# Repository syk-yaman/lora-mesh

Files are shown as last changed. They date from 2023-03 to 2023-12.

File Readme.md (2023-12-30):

# LoRaMesh: a LoRa mesh network deployed in the Olympic Park, London to sense weather parameters

##### A dissertation for an MSc degree in [Connected Environments](https://connected-environments.org/) at [University College London](https://www.ucl.ac.uk/prospective-students/graduate/taught-degrees/connected-environments-msc), 2022/2023.

This project uses [OpenThread](https://openthread.io/) in LoRa to sense humidity, temperate and light in the Queen Elizabeth Olympic Park (QEOP), London. Sensor data is visualised via web dashboards and projected on a physical Olympic Park table using projection mechanism.

| Mesh node | The Data Table |
| :---: | :---: |
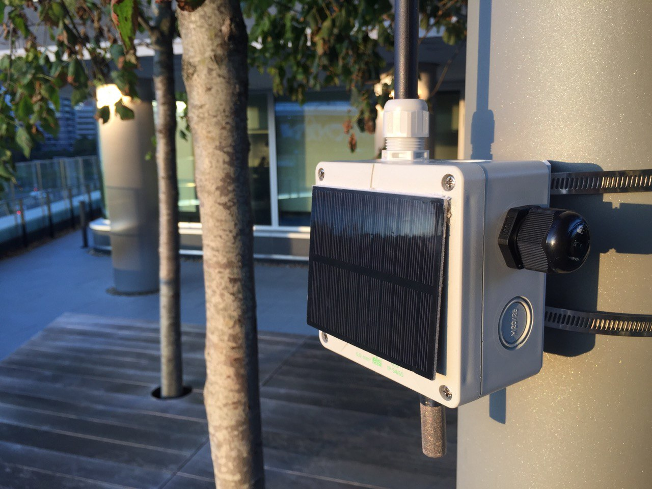
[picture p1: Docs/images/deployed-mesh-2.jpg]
Deployed mesh node in the Olympic Park
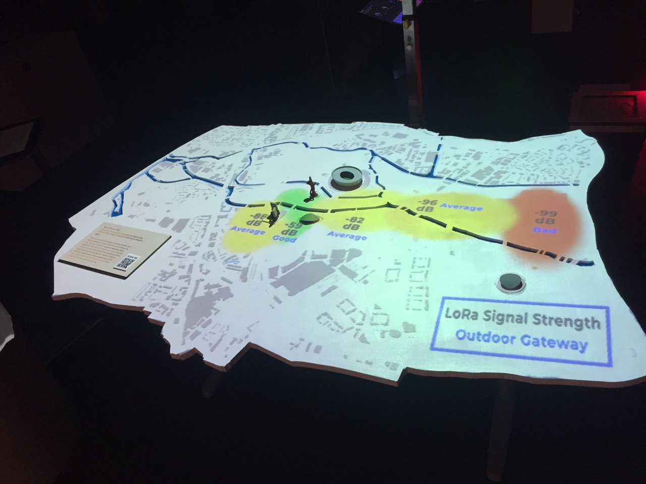
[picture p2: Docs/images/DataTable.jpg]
The Data Table
|  |  |

## Repository Content Summary

1. **Assets**

   This folder includes the 3D printed parts, namely Fusion360 project files and STLs for the enclosures and the 3D objects for the Data Table.

   - [QEOP 3D Models](</Assets/QEOP 3D models/>)
   - [LoRa Gateway 3D Enclosures](</Assets/3D Enclosures/>)

2. **Code**

   Includes micro-controllers' code, Artificial Intelligence code and various assets used during development.

   - [Lopy4](/Code/Lopy4)

     The main Micro Python code for the Lopy4, which uses Open Thread for LoRa mesh.

   - [Current Analysis](/Code/Current%20Analysis)

     Contains the code, schematic and results for the real-time current analysis circuit.

   - [Heatmap](/Code/Heatmap)

     Web page that visualises CSV data for LoRa heatmap in the Olympic Park.

   - [VR Headset](/Code/VR%20Headset)

     A web page built using [A-Frame](https://aframe.io/) to visualise 360 videos of the QEOP on VR Headsets.

   - [Data Table](</Code/DataTable>)
     The data files projected on the physical map including the final calibrated [Base Map](/Code/DataTable/BaseMap.jpg).

3. **Datasets**

   The final datasets as an outcome of this project. There is a [detailed description](/Datasets/Readme.md) available for each dataset.
   
4. **Docs**

   This folder holds different kinds of documentation and images produced during project life time.

5. **PCB**

   The electronic side of the project. This section contains Eagle files and CAM outputs sent to PCB manufacturers. Also, a [CNC manufacturing tutorial](/PCB/CNC) is available.

6. **Server**

   Docker Composer file for InfluxDB, Grafana and MQTT broker. Basically, all data acquisition is being managed by this Docker image.

7. **Experiments**
   This section includes the multiple experiments done throughout the project.

   - [Experiment #1](/Experiments/Experiment1): First heatmap between LoRa indoor gateway and MRK1310.
   - [Experiment #2](/Experiments/Experiment2): Heatmap between two LoRa nodes (Both MRK1310).
   - [Experiment #3](/Experiments/Experiment3): Heatmap between two LoRa nodes (Both Lopy4), contains a [geolocated dataset](/Experiments/Experiment3/Results/heatmap/Experiment3-LoRa-RSSI-heatmap-QEOP-OPS.csv).
   - [Experiment #4](/Experiments/Experiment4): Contains a [topographic study](/Experiments/Experiment4/GIS%20Stratford) using QGIS, and a [detailed deployment plan](/Experiments/Experiment4/Deployment%20plan) for LoRa nodes in the QEOP.
   - [Experiment #5](/Experiments/Experiment5): Basic Pymesh experiments. 
   - [Experiment #6](/Experiments/Experiment6): Basic MQTT experiments.

## Project Overview

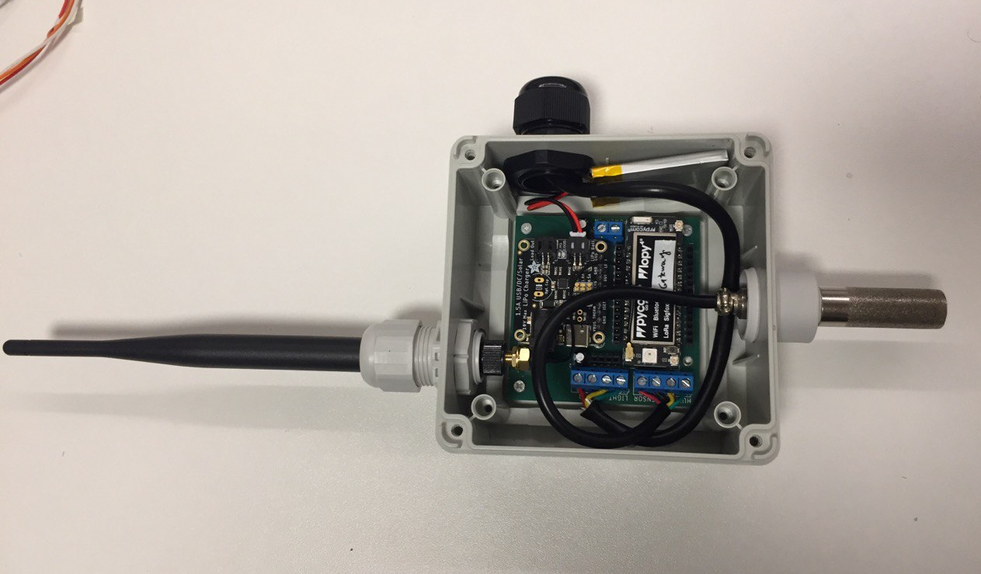
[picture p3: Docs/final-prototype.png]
Final prototype


<p align="center">
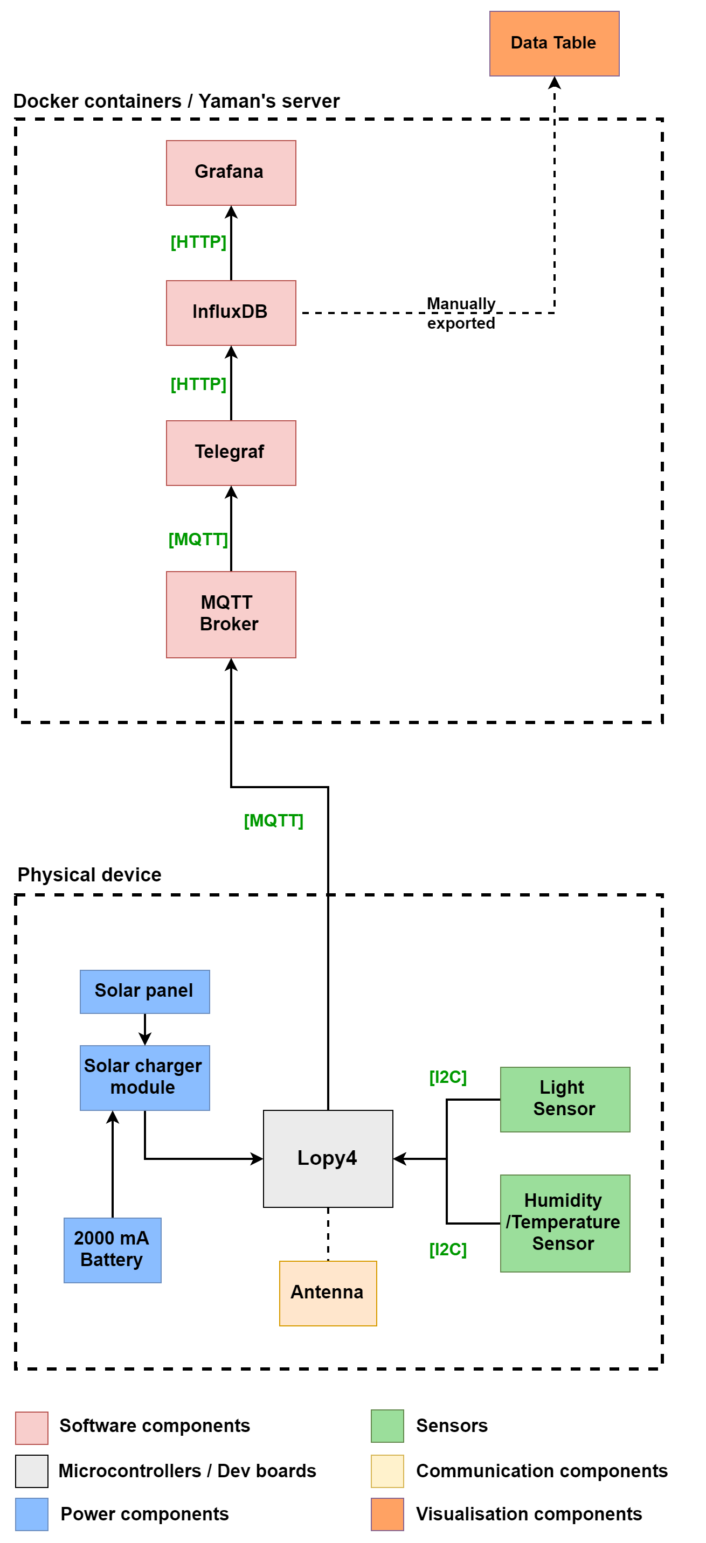
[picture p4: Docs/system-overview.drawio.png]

</p>

## Building

### Used components and tools

Hardware:

* [Lopy4](https://www.adafruit.com/product/3689): a dev kit based on ESP32 that has LoRa, Wifi, Sigfox and Bluetooth communication capability.
* [SHT-30](https://www.adafruit.com/product/4099): a weatherproof humidity and temperature sensor.
* [Gravity SEN0562](https://www.dfrobot.com/product-2664.html): a weatherproof light sensor.
* [DC Solar charger (BQ24074)](https://www.adafruit.com/product/4755)
* [Solar panel](https://coolcomponents.co.uk/products/solar-panel-1-watt): 1 Watt, 10x80 cm.
* 2000 mA 3.7v battery

Software:

 - [InfluxDB](https://www.influxdata.com/)
 - [Telegraf](https://www.influxdata.com/time-series-platform/telegraf/)
 - [Grafana](https://grafana.com/)
 - [Docker Compose](https://docs.docker.com/compose/)

All the software applications are packed into one [Docker image](/Server/docker-compose.yml) that you can use easily.

### Hardware PCB and schematic

<p align="center">
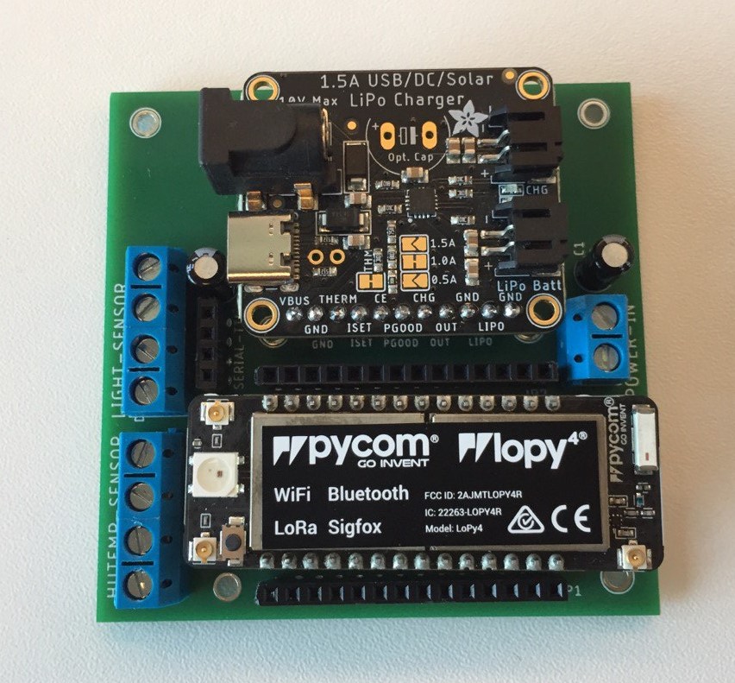
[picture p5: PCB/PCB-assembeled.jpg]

</p>

<p align="center">
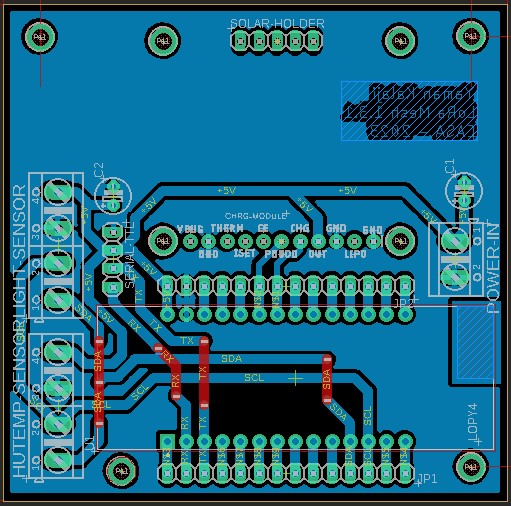
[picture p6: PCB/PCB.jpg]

</p>

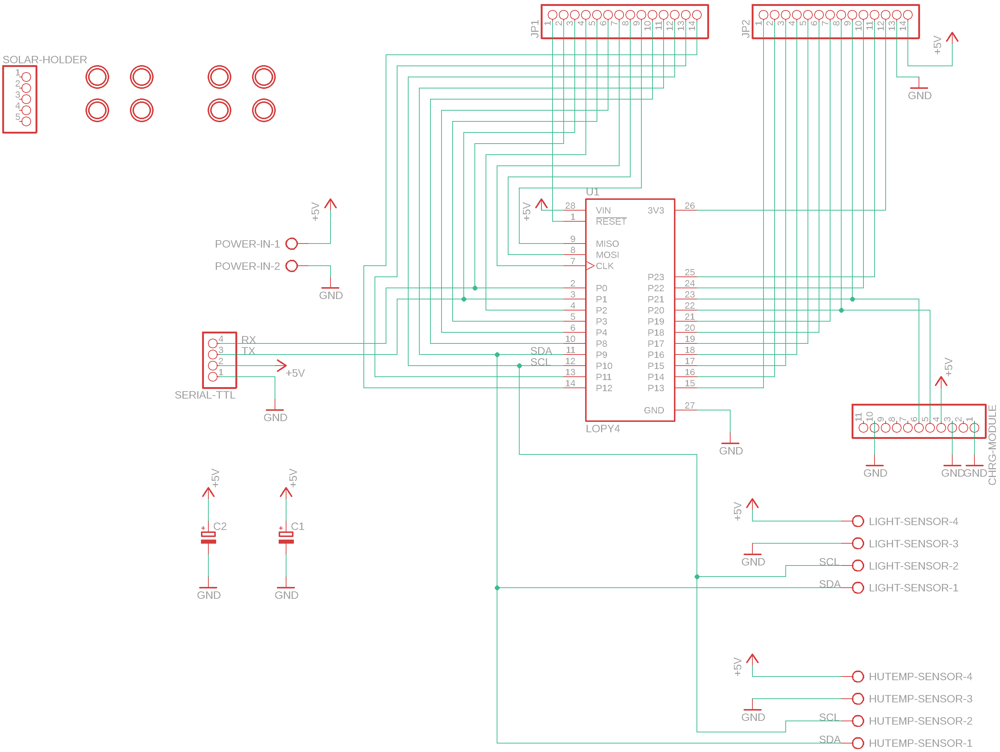
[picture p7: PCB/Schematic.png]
Hardware schematic


## Results

#### The Data Table

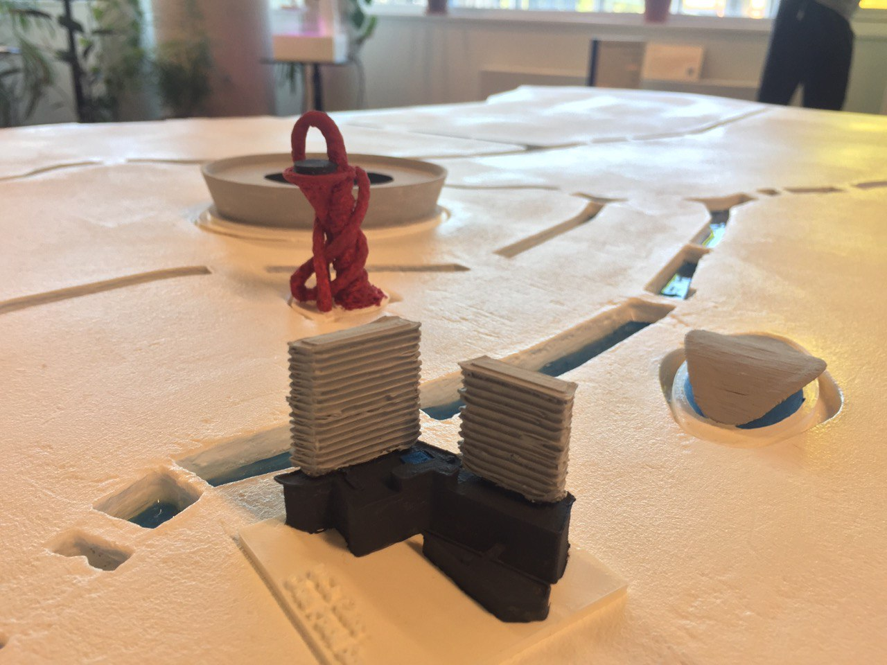
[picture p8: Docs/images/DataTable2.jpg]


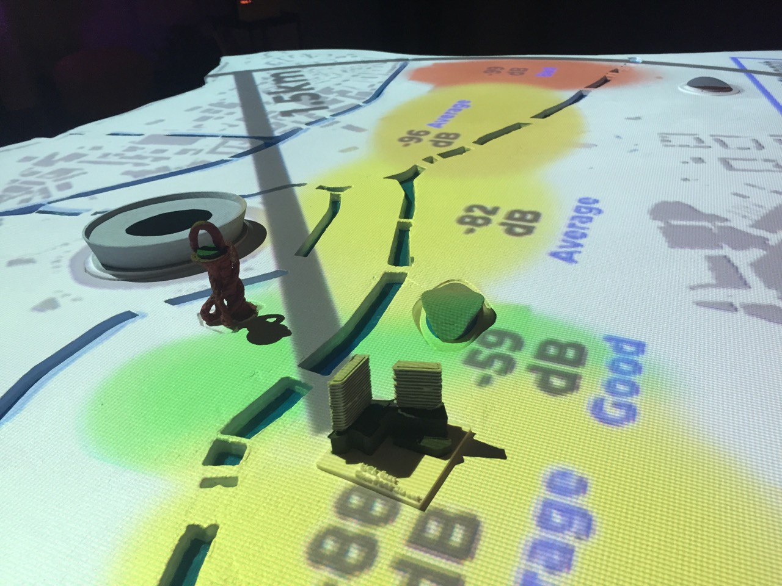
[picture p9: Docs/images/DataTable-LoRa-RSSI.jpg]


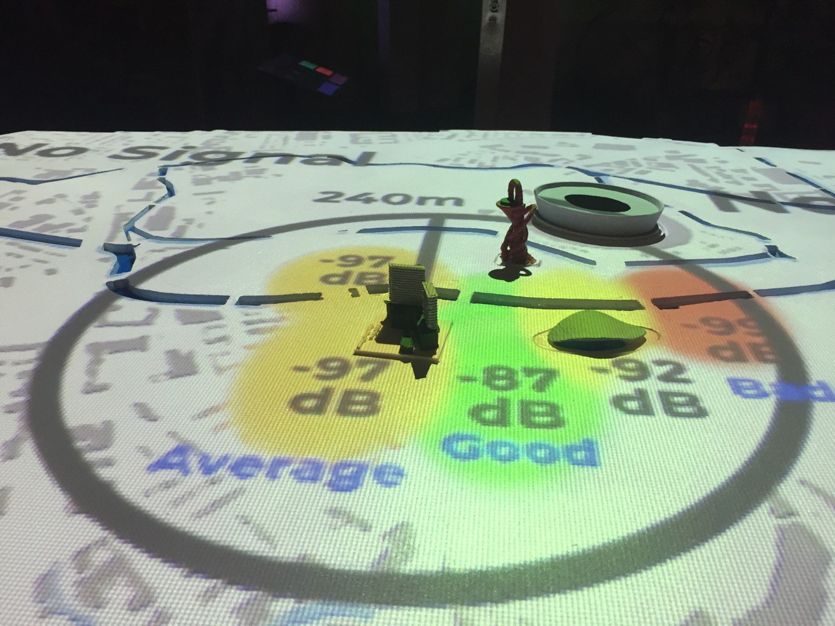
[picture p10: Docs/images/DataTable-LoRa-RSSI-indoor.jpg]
 



#### Grafana Dashboard

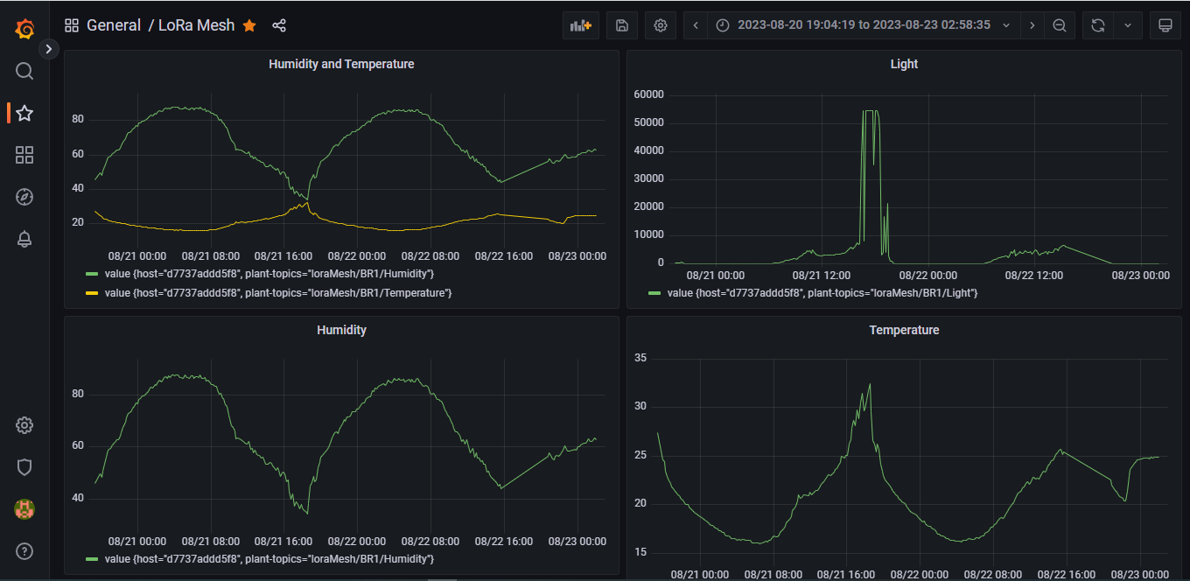
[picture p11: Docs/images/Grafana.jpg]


#### Heatmaps

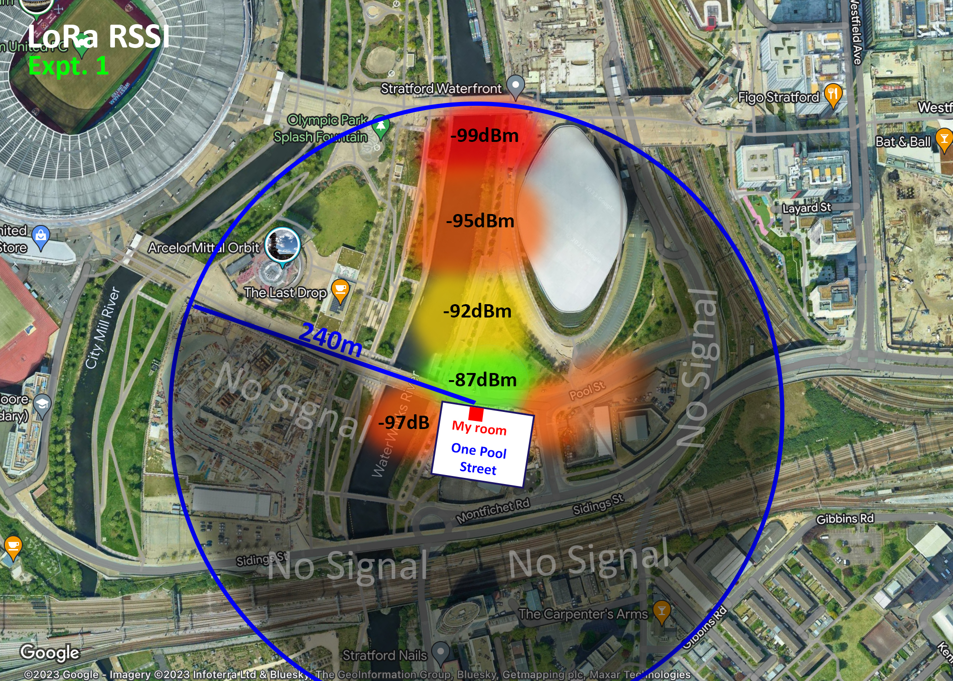
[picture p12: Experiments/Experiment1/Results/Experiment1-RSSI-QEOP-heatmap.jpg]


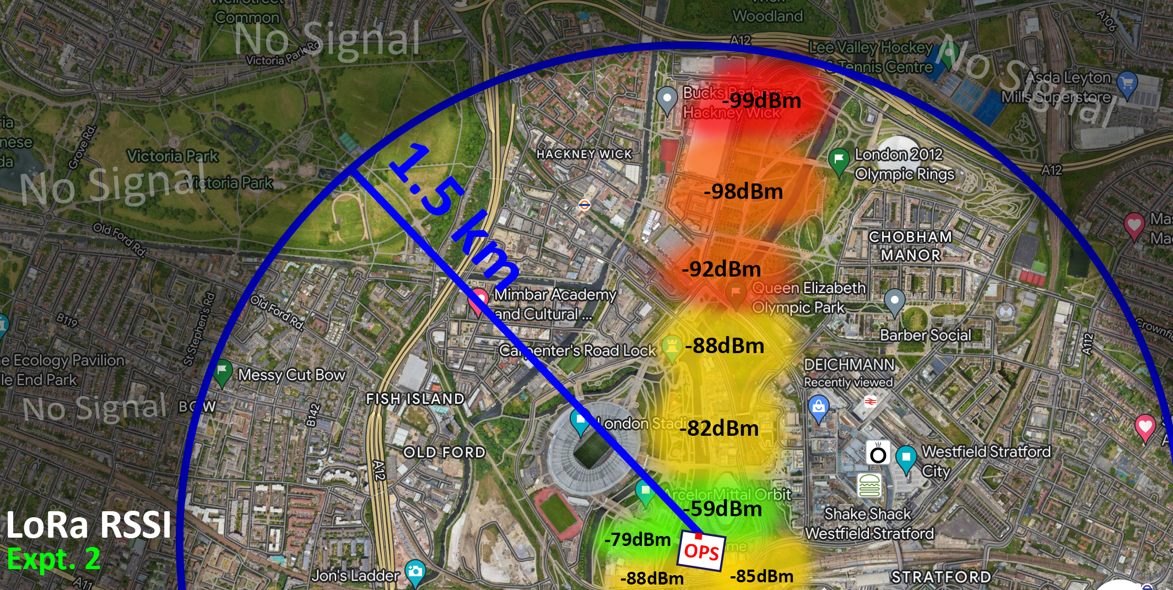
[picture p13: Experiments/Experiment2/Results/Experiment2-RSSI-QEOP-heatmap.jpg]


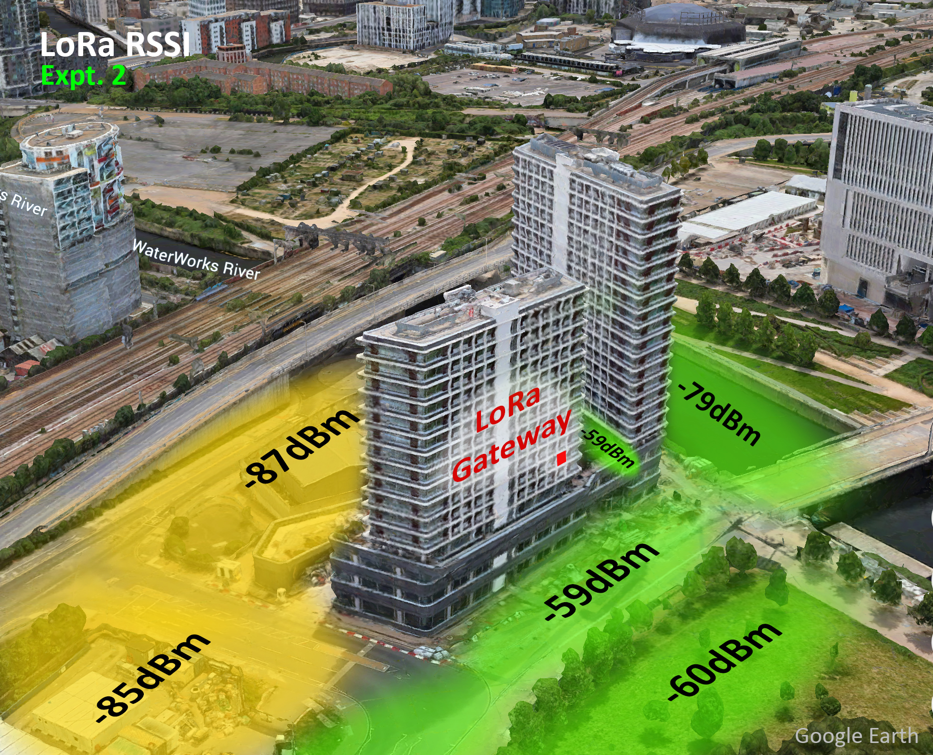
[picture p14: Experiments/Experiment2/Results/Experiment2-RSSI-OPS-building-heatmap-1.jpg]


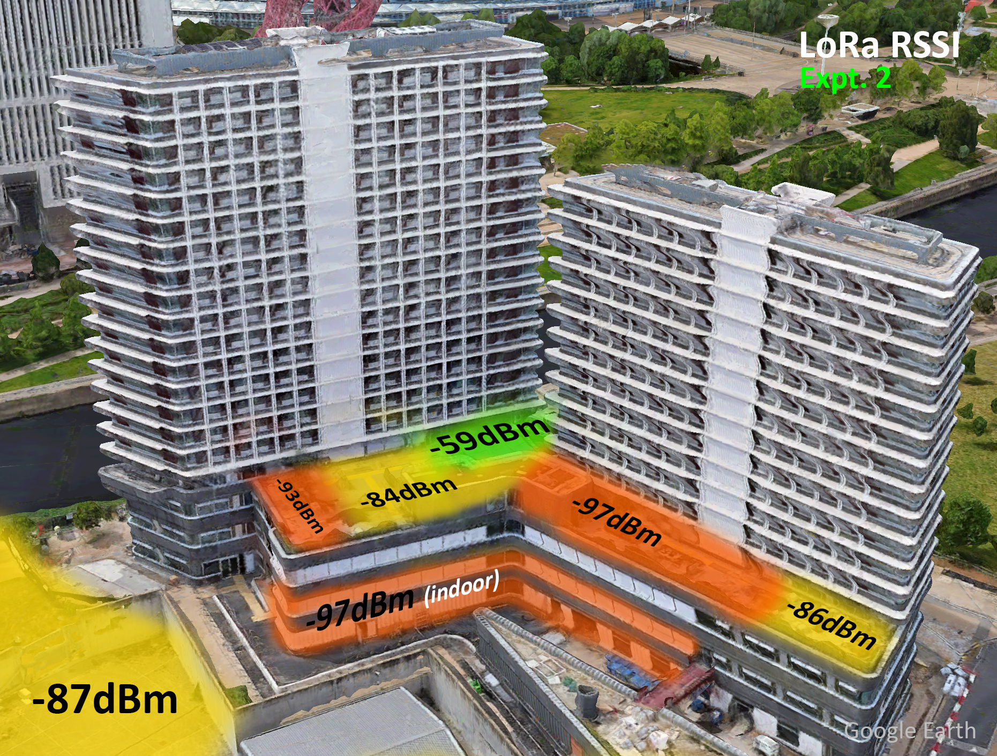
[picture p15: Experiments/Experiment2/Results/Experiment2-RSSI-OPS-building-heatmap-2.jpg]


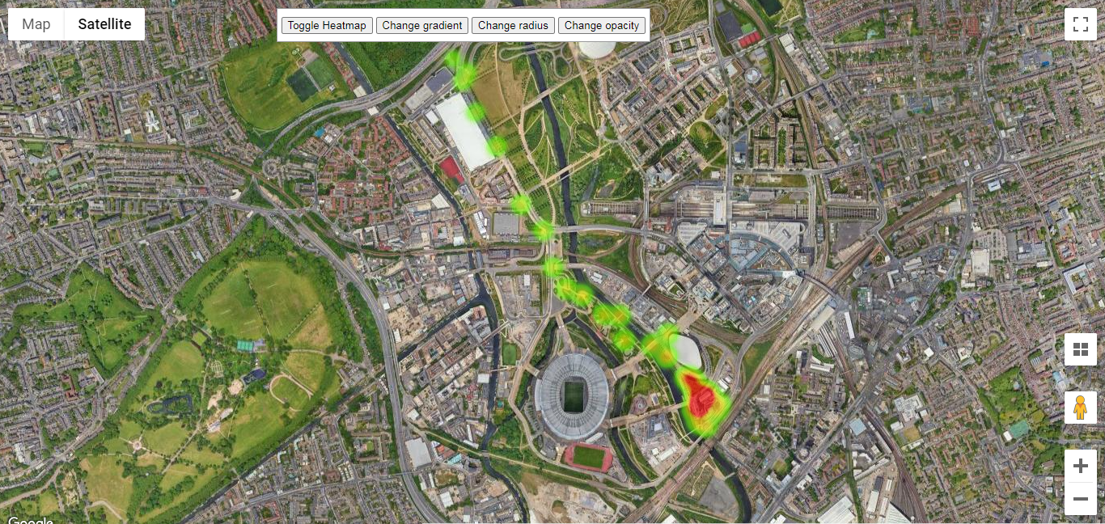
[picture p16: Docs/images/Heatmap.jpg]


#### Current consumption analysis

<p align="center">
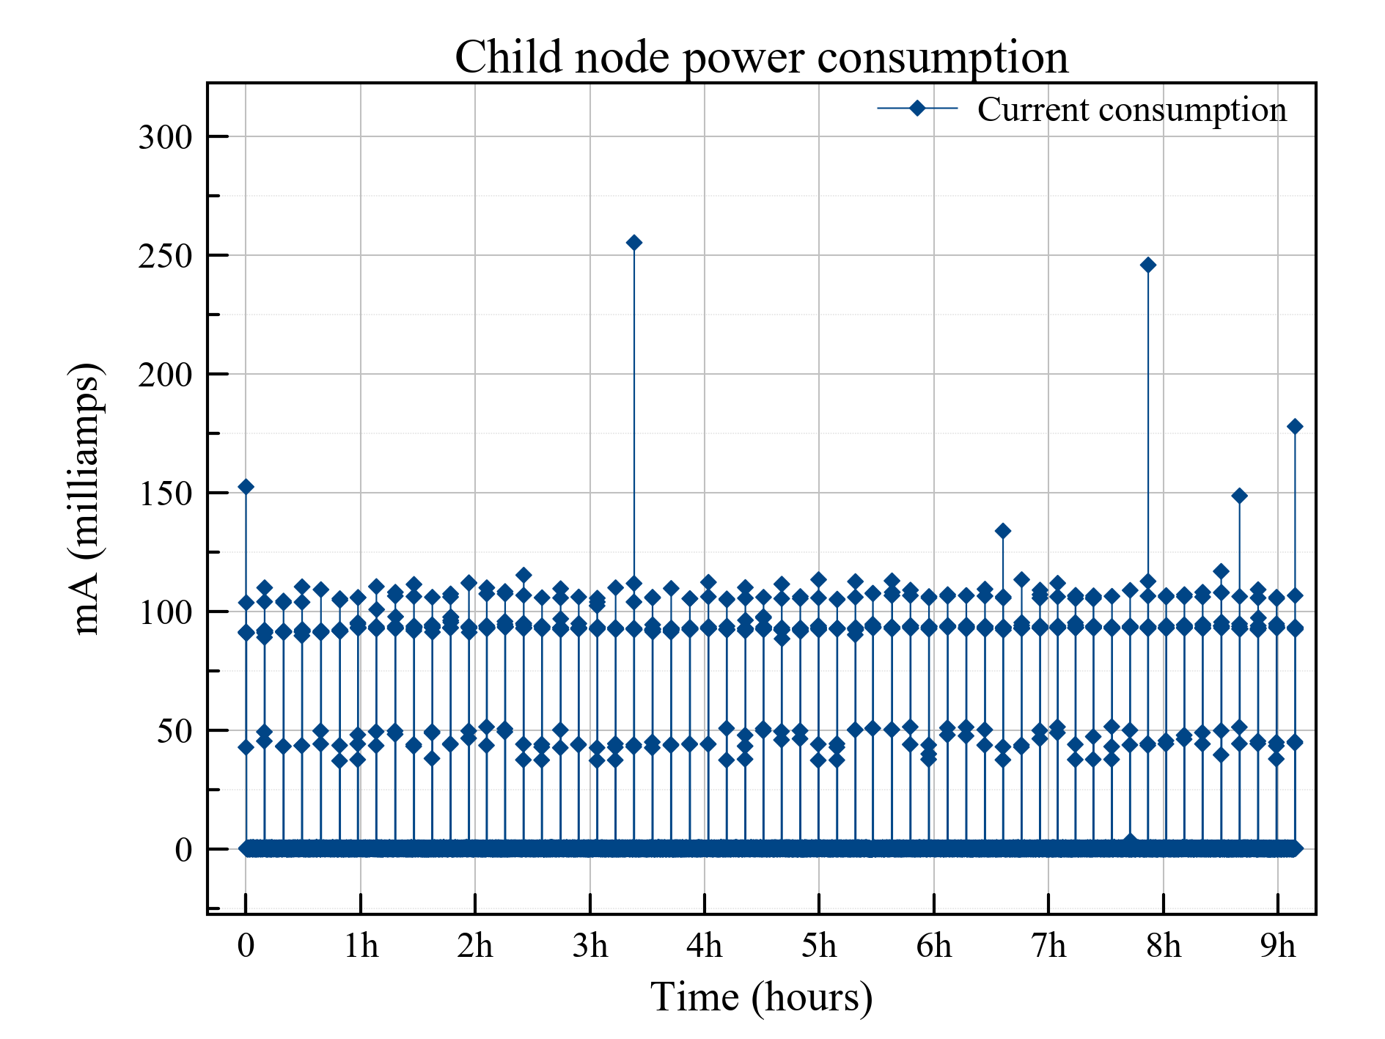
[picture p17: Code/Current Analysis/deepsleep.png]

</p>

<p align="center">
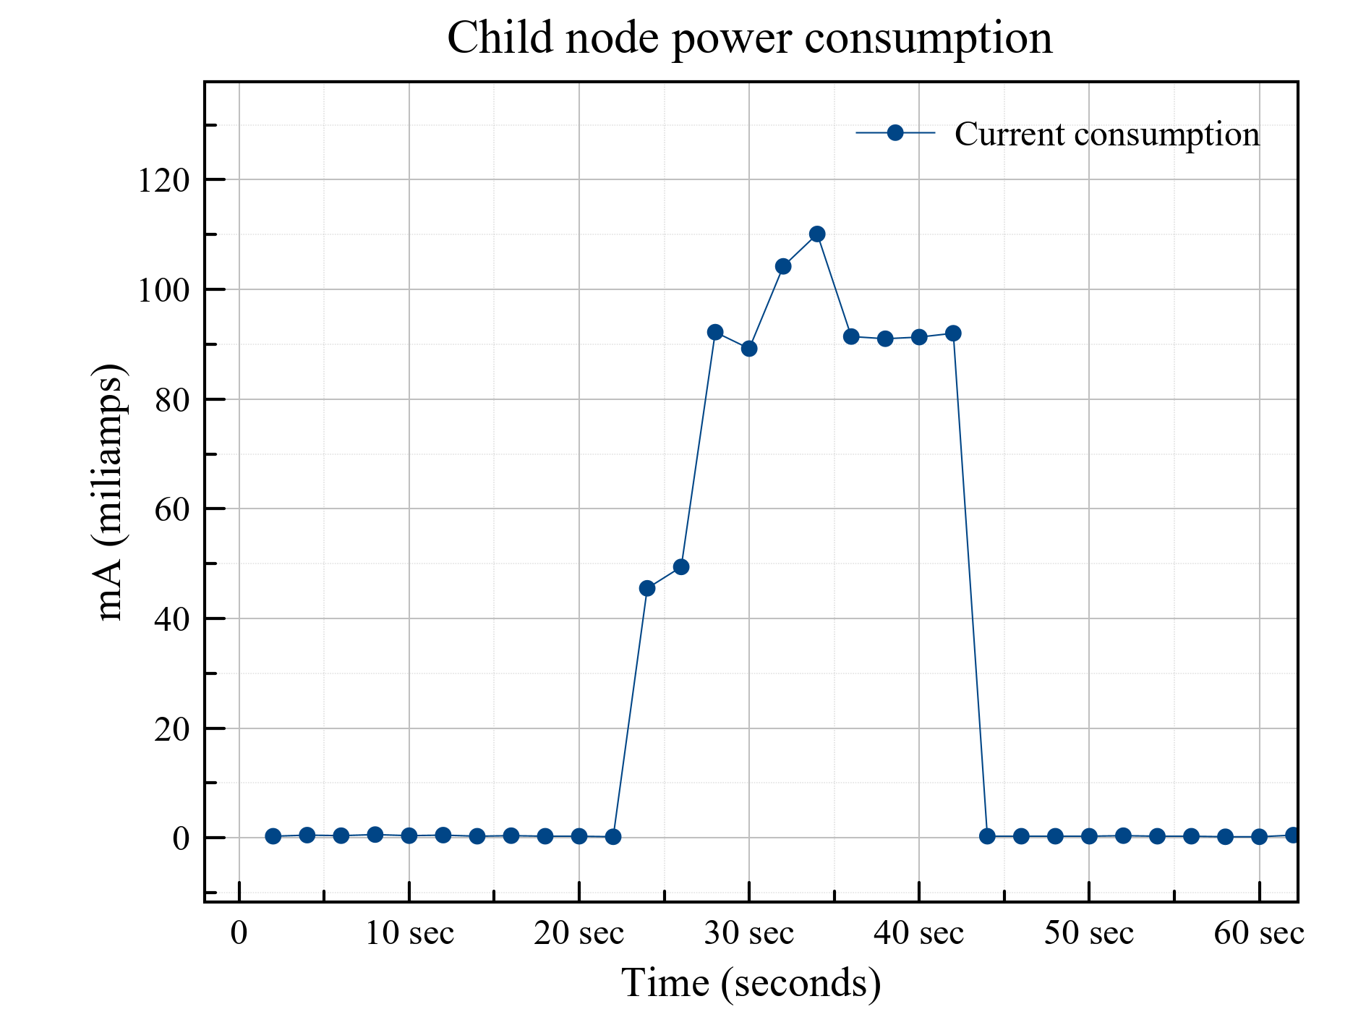
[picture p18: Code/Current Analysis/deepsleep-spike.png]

</p>

<p align="center">
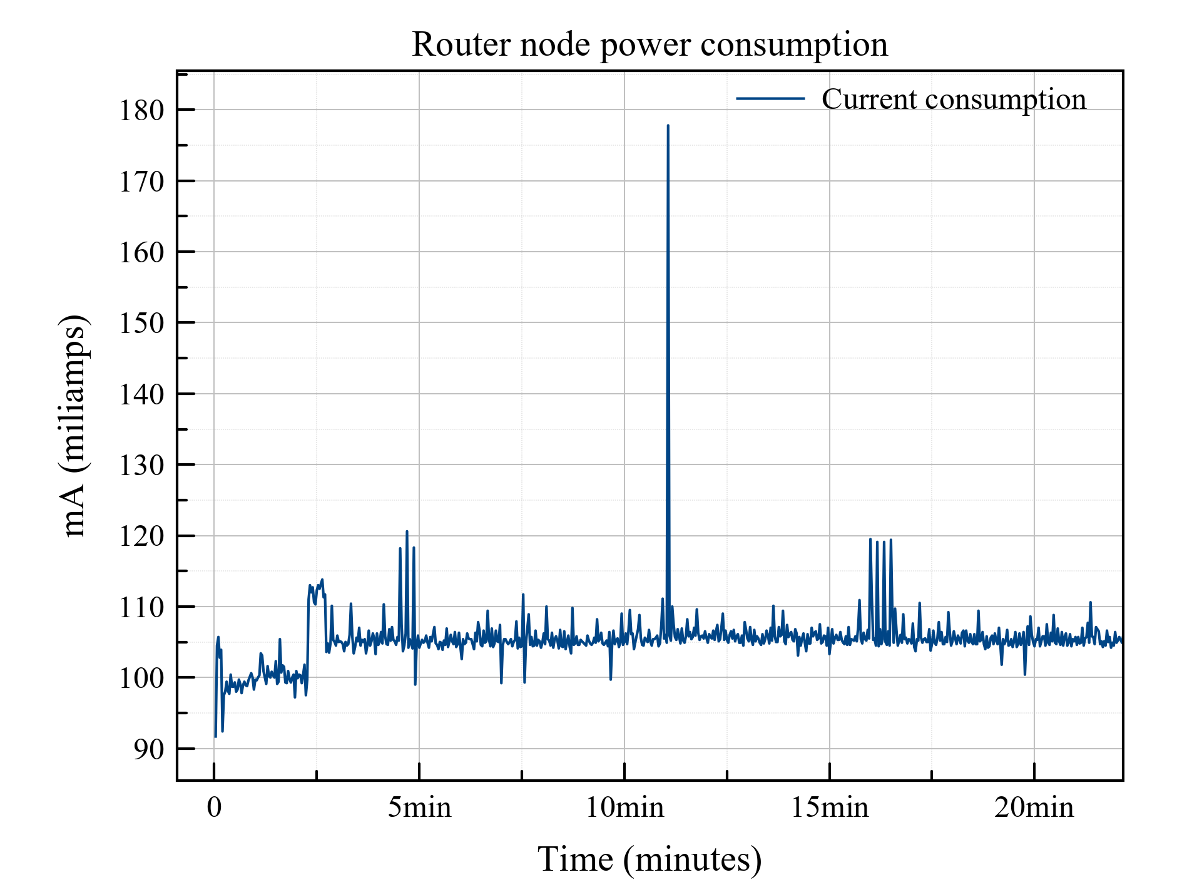
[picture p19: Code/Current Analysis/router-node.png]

</p>

## License

###### The software side is licensed under MIT License

```
MIT License

Permission is hereby granted, free of charge, to any person obtaining a copy
of this software and associated documentation files (the "Software"), to deal
in the Software without restriction, including without limitation the rights
to use, copy, modify, merge, publish, distribute, sublicense, and/or sell
copies of the Software, and to permit persons to whom the Software is
furnished to do so, subject to the following conditions:

The above copyright notice and this permission notice shall be included in all
copies or substantial portions of the Software.

THE SOFTWARE IS PROVIDED "AS IS", WITHOUT WARRANTY OF ANY KIND, EXPRESS OR
IMPLIED, INCLUDING BUT NOT LIMITED TO THE WARRANTIES OF MERCHANTABILITY,
FITNESS FOR A PARTICULAR PURPOSE AND NONINFRINGEMENT. IN NO EVENT SHALL THE
AUTHORS OR COPYRIGHT HOLDERS BE LIABLE FOR ANY CLAIM, DAMAGES OR OTHER
LIABILITY, WHETHER IN AN ACTION OF CONTRACT, TORT OR OTHERWISE, ARISING FROM,
OUT OF OR IN CONNECTION WITH THE SOFTWARE OR THE USE OR OTHER DEALINGS IN THE
SOFTWARE.
```

###### The hardware side is licensed under CERN License

```
This documentation describes Open Hardware and is licensed under the CERN OHL v. 1.2.

You may redistribute and modify this documentation under the terms of the CERN OHL v.1.2. (http://ohwr.org/cernohl). This documentation is distributed WITHOUT ANY EXPRESS OR IMPLIED WARRANTY, INCLUDING OF MERCHANTABILITY, SATISFACTORY QUALITY AND FITNESS FOR A PARTICULAR PURPOSE. Please see the CERN OHL v.1.2 for applicable conditions
```

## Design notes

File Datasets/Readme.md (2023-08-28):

# Datasets description

| Dataset name | Description | Unit | Related to | Visualisation |
| :---: | :---: | --- | --- | --- |
| [LoRa-RSSI-heatmap-QEOP-OPS-Lopy4.csv](/Datasets/LoRa-RSSI-heatmap-QEOP-OPS-Lopy4.csv) | An RSSI heatmap in the Queen Elizabeth Olympic Park, London between two LoRa nodes (Pycom Lopy4).<br />The first node is static on the 5th floor at One Pool Street building (Tower 2), the second one is portable. | dBm | [Experiment #3](/Experiments/Experiment3) | <br />[Heatmap webpage](/Code/Heatmap)<br /><br /><br /><br />[DataTable](/Code/DataTable) |
| [Current-Analysis-Border-Router-Node.csv](/Datasets/Current-Analysis-Border-Router-Node.csv) | Current consumption in mA for a border router node in the LoRa mesh network | mA | [Current Analysis](/Code/Current%20Analysis) |  |
| [Current-Analysis-Child-Node-with-deep-sleep.csv](/Datasets/Current-Analysis-Child-Node-with-deep-sleep.csv) | Current consumption in mA for a child node router in the LoRa mesh network (with two sensors attached) | mA | [Current Analysis](/Code/Current%20Analysis) | <br /><br /> |
| [Humditiy-QEOP-2023-08-20-to-2023-08-23.csv](/Datasets/Humditiy-QEOP-2023-08-20-to-2023-08-23.csv) | Outdoor humidity readings in the Queen Elizabeth Olympic Park, London. Sensor deployed in One Pool Street building | RH (%) | N/A |  |
| [Temperature-QEOP-2023-08-20-to-2023-08-23.csv](/Datasets/Temperature-QEOP-2023-08-20-to-2023-08-23.csv) | Outdoor temperature readings in the Queen Elizabeth Olympic Park, London. Sensor deployed in One Pool Street building | Celsius  | N/A |  |
| [Light-QEOP-2023-08-20-to-2023-08-23.csv](/Datasets/Light-QEOP-2023-08-20-to-2023-08-23.csv) | Outdoor light readings in the Queen Elizabeth Olympic Park, London. Sensor deployed in One Pool Street building | Lux (lx) | N/A |  |

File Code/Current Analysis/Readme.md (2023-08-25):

Current measurment interval is 2 seconds

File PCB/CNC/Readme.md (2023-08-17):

## Guidelines for PCB Manufacturing using a CNC:

This is a general guide how to manufacture a PCB using a CNC. This guideline is also available and being always updated on [LoRa Mesh Github Repo](https://github.com/syk-yaman/lora-mesh/tree/master/PCB/CNC).

### Tools needed/used:

1. CNC machine: [Carvey](http://carvey-instructions.inventables.com/) from Inventables is used for this manual.
2. [FlatCam](http://flatcam.org/) to convert Gerber files to G-code. **Important note:** Only FlatCam v8.5 is compatible with Carvey machines, you can download the older version from [here](https://bitbucket.org/jpcgt/flatcam/downloads/).
3. [Autodesk Eagle](https://www.autodesk.com/products/eagle/overview?term=1-YEAR&tab=subscription) or any PCB CAD software, this method works for all of them!
4. [Easel software](https://easel.inventables.com/) to connect to the Carvey CNC machine, it's a web application without installation. A free plan would probably works fine.

### Steps in Eagle:

After finishing your design and heading to the CAM Processor, choose the `example_2_layer.cam`.

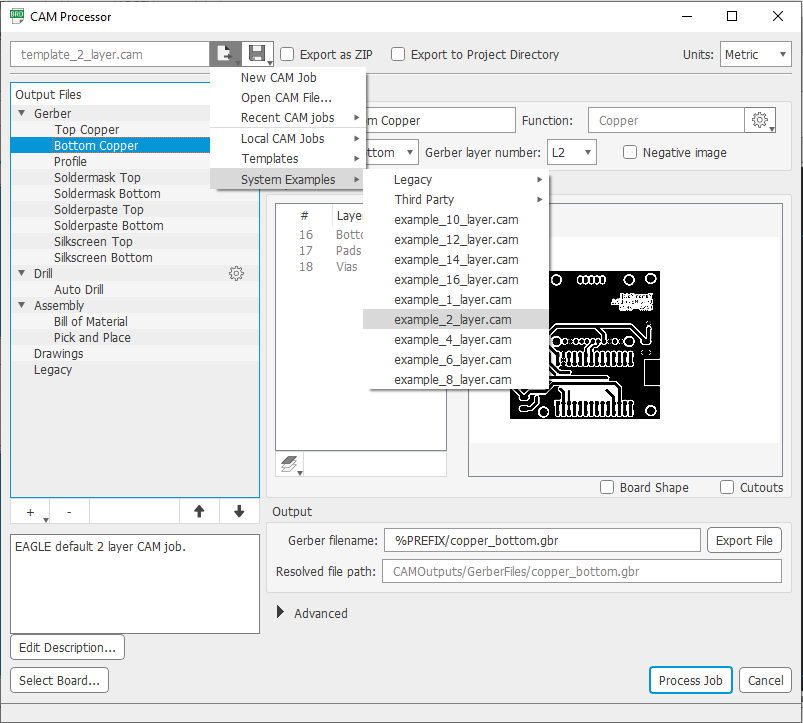
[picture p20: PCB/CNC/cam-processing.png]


After processing the job, the output files that we are interested in are:

- `copper_bottom.gbr` in `GerberFiles` folder.
- `copper_top.gbr` in `GerberFiles` folder, if it's a two-layers PCB.
- `drill_1_16.xln` in `DrillFiles` folder.

Those files are to be imported to FlatCam.

### Steps in FlatCam:

Basically, it's best to follow this video:

[How NOT to Mill a PCB (except for SMD)](https://www.youtube.com/watch?v=_ak0IJUMBFg)

And for extra information, those videos could also be assisting:

[CNC Milling Double Sided PCBs Using Eagle, FlatCam and GRBL/Candle, Step by Step Detailed Guide](https://www.youtube.com/watch?v=9xczeQMj2dg&t=375s)

[Eagle CadSoft + FlatCam CNC Gcode](https://www.youtube.com/watch?v=p3YzVjpt9Ig&t=794s)

#### Important notes:

1. **Don't forget** to mirror the bottom layer, this is not mentioned in the previous videos.

2. For the Carvey CNC, please change these settings as follows:

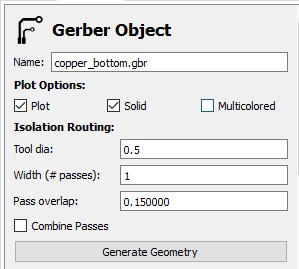
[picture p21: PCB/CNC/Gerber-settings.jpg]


Some explanations:

* **Tool dia**: diameter of the cutting tool, to be changed **<u>once for every generated G-code</u>**, this means if you have multiple paths with multiple widths, you need to create a G-code for each separately. 

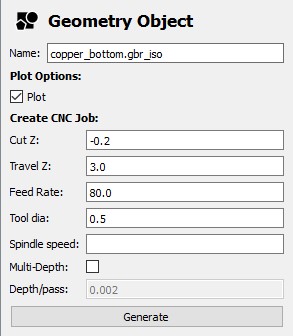
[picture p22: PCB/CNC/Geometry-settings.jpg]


Some explanations:

- **Cut Z**: this is related to the height between the drilling bit and the PCB, which is according to my experiments should be -0.2. If you notice the drilling bit is not touching the PCB, or the copper layer gets pushed too much, try to adjust this accordingly.
- **Travel Z**: the height of the drill when it moves from one position to another on the PCB. Making this 3 helps in taking less time.
- **Feed Rate**: cutting speed, try to lower it down if you notice the copper edges are not smooth enough.
- **Tool dia**: this is just for display, it was originally set in the previous photo.  

### Steps in Easel:

Basically, just import the generated G-code from FlatCam to Easel. No need for any further settings here, the imported G-code contains all the required settings. Hit Carve and go! - don't forget to watch the first couple of minutes to make sure the CNC is executing the job correctly.

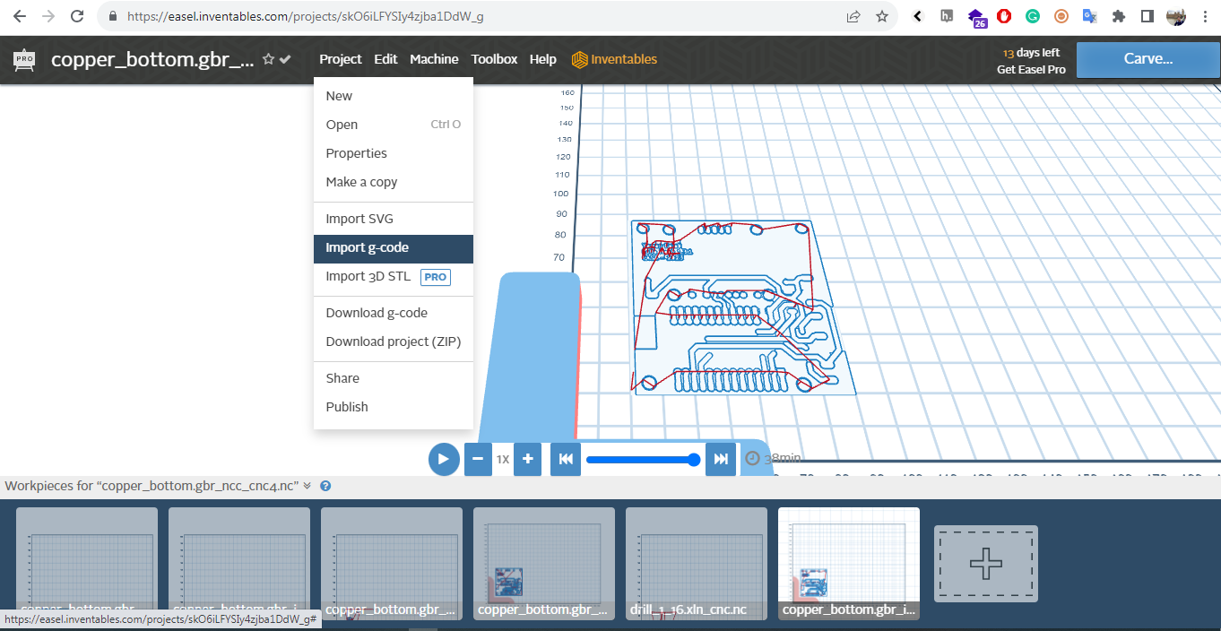
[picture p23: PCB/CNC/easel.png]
easel


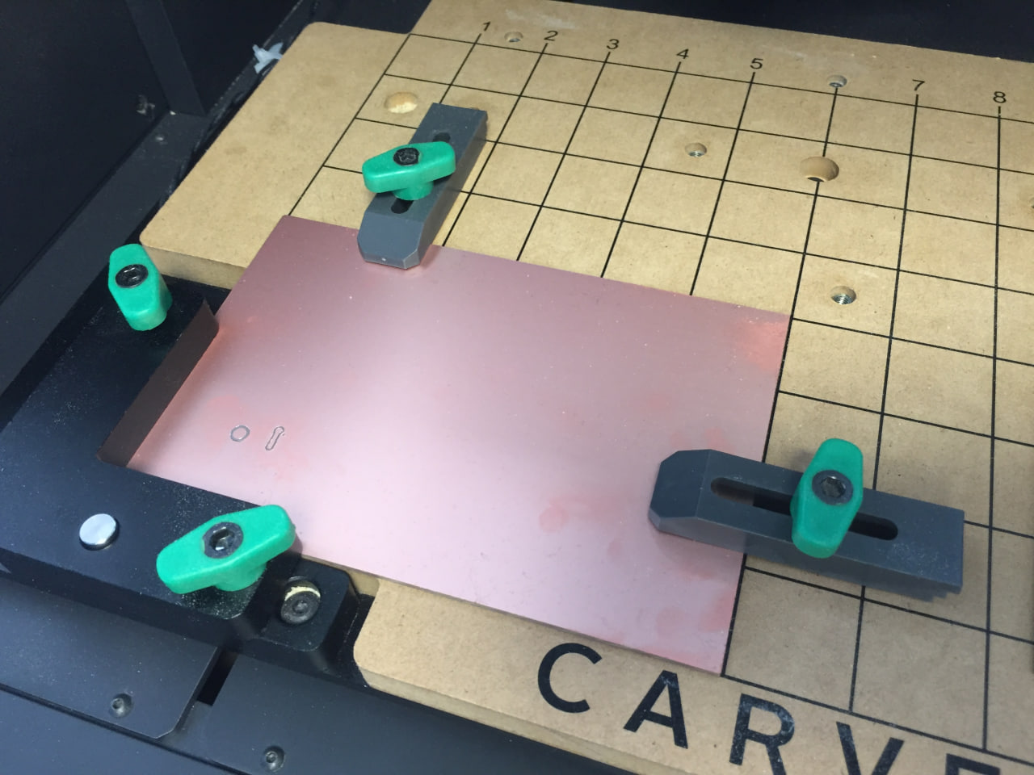
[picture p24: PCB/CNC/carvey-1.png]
carvey-1


**Note:** try to not fix the PCB from its edges but only from long edges, as doing this would make it curve from the centre thus not having the same height everywhere.

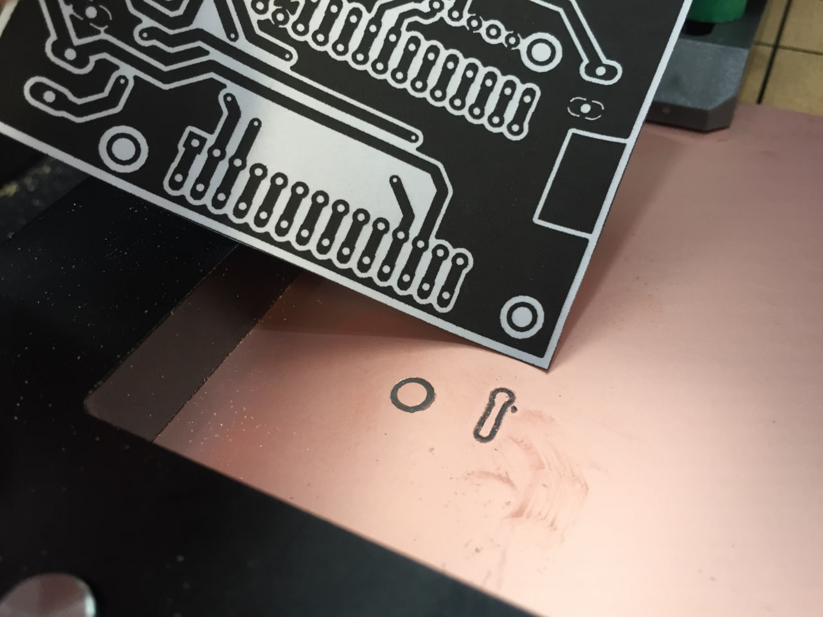
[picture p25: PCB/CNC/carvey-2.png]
carvey-2


## Further notes to be added after continuing the experiments.

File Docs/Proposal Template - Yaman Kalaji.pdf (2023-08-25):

### Working Title

Power analysis of an autonomous LoRa mesh network for rural agriculture environment

### Hypothesis or Research Question

Can we rely on an autonomous LoRa mesh sensor network to work efficiently in distant areas without network or electricity infrastructure? What is the power performance of mesh nodes in this case?

### Background

LoRa sensor networks work best when surrounded by gateways, but this tends to be difficult or extremely costly in certain situations where no network or electrical infrastructure is available, such as vast and remote agriculture lands, oil pipelines, underground tunnels or deserts (Pagano et al., 2022). Research community is currently trying to investigate the practicality of using LoRa mesh networks to achieve lower costs and more dynamic deployments (Marahatta et al., 2021; Nurgaliyev et al., 2020)

In previous studies, the analysis of LoRa mesh networks has taken several factors into consideration; security, communication, power, cost and scalability (Cotrim and Kleinschmidt, 2020). This research is focused on analysing the power factor using agriculture as a case study. Although there were multiple earlier studies in this field (Rodríguez-Robles et al., 2020; Suji Prasad et al., 2022; Codeluppi et al., 2020), they seemed to have focused on the networking side of mesh networks more than studying the power performance of the autonomous sensors.

In this research, energy harvesting would be used at end nodes in addition to specific algorithms to optimise the power efficiency of the mesh network in the selected case study.

### Research Design (Sense, Deploy, Communicate)

The project includes designing a small cluster of devices to sense one or multiple agriculture parameters, such as; air humidity, air temperature, light, and soil moisture. Each of these devices consists of LoRa-powered devices with the previous sensors, a battery, and a small solar panel. All nodes will be deployed in the QEOP and will be using a private gateway to communicate their data to the outer internet.

Technical details:

Nodes will use the ESP32-based Lopy4 modules (Pycom, 2023) with an auxiliary solar charging module, in addition to one or more related sensors. Nodes will use the powerful Pycom Pymesh (2023) library which supports multiple mesh topologies, and those nodes will be able to take decisions to alter their behaviour according to their power consumption. All nodes will be sending their data through each other to a Mikrotik LoRa gateway (Mikrotik, 2023). Sensors’ readings will be stored in an InfluxDB hosted on a private server on the internet to be visualised later through Grafana or custom web dashboards.

### Timetable

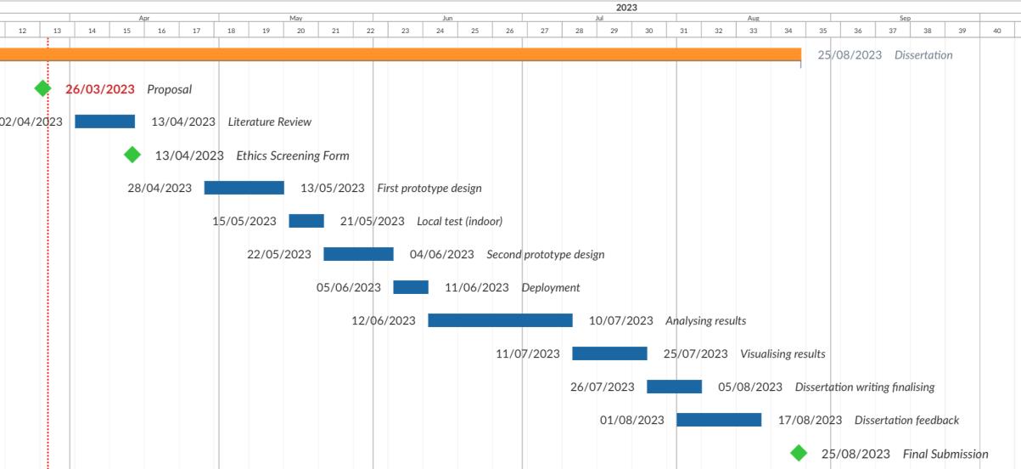
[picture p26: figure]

### References

Codeluppi, G., Cilfone, A., Davoli, L. and Ferrari, G., 2020. LoRaFarM: A LoRaWAN-based smart farming modular IoT architecture. Sensors, 20(7), p.2028.

Cotrim, J.R. and Kleinschmidt, J.H., 2020. LoRaWAN mesh networks: A review and classification of multihop communication. Sensors, 20(15), p.4273.

Mikrotik (2023) KNOT LR8 Kit. Available at: https://mikrotik.com/product/knot_lr8 (Accessed: 26 March 2023)

Marahatta, A., Rajbhandari, Y., Shrestha, A., Singh, A., Thapa, A., Gonzalez-Longatt, F., Korba, P. and Shin, S., 2021. Evaluation of a lora mesh network for smart metering in rural
locations. Electronics, 10(6), p.751.

Nurgaliyev, M., Saymbetov, A., Yashchyshyn, Y., Kuttybay, N. and Tukymbekov, D., 2020. Prediction of energy consumption for LoRa based wireless sensors network. Wireless Networks, 26, pp.3507-3520.

Pagano, A., Croce, D., Tinnirello, I. and Vitale, G., 2022. A Survey on LoRa for Smart Agriculture: Current Trends and Future Perspectives. IEEE Internet of Things Journal.

Pycom (2023) Lopy4. Available at: https://docs.pycom.io/datasheets/development/lopy4/(Accessed: 26 March 2023)

Pycom Pymesh (2023) Pymesh. Available at: https://docs.pycom.io/pymesh/ (Accessed: 26 March 2023)

Rodríguez-Robles, J., Martin, Á., Martin, S., Ruipérez-Valiente, J.A. and Castro, M., 2020. Autonomous sensor network for rural agriculture environments, low cost, and energy selfcharge. Sustainability, 12(15), p.5913

Suji Prasad, S.J., Thangatamilan, M., Suresh, M., Panchal, H., Rajan, C.A., Sagana, C., Gunapriya, B., Sharma, A., Panchal, T. and Sadasivuni, K.K., 2022. An efficient LoRa-based smart agriculture management and monitoring system using wireless sensor networks. International Journal of Ambient Energy, 43(1), pp.5447-5450.

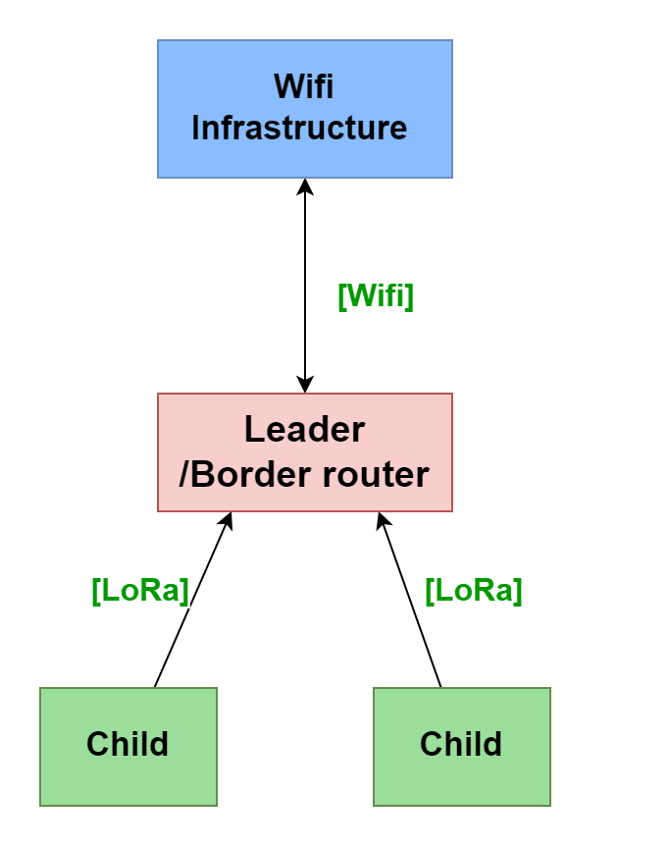
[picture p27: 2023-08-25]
Docs/system-overview-Page-2.drawio (1).png

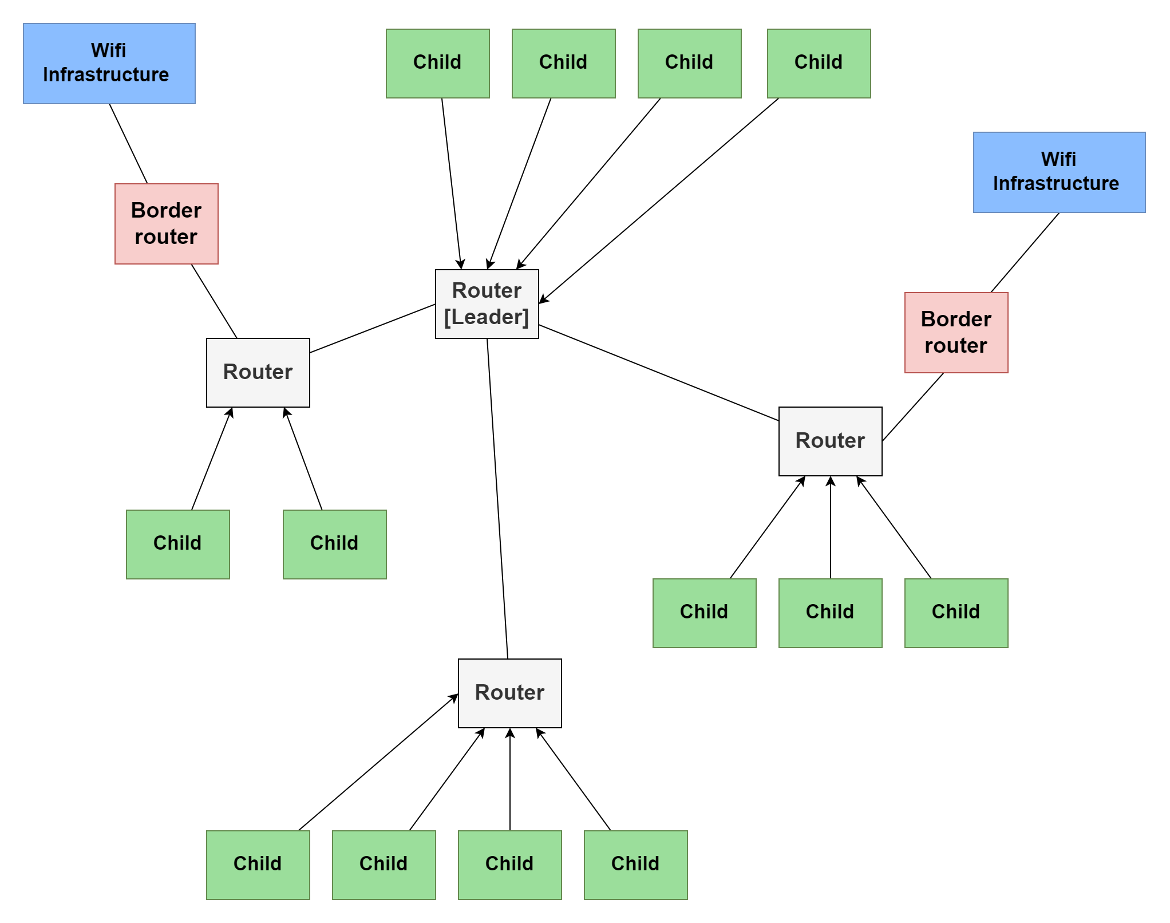
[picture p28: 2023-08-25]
Docs/system-overview-Page-2.drawio.png

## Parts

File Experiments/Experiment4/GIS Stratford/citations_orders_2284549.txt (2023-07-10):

The citations in this document should be used to reference the maps and data
when they have been included in any essays, dissertations or other academic
works. You should cite the data even if it doesn't appear as an image or map
in your work if it has been used to generate findings or a new dataset that is
used.

There is one entry for each product and selected area; you can edit the
citation if you only use part of the data it covers. Any citations provided
below are a guide only and should be given in addition to any requirement to
acknowledge sources and copyright of any data used or any local guidance
provided:

OS VectorMap® Local [TIFF geospatial data], Scale 1:10000, Tiles: tq38ne_clipped,tq38se_clipped, Updated: 1 April 2023, Ordnance Survey (GB), Using: EDINA Digimap Ordnance Survey Service, <https://digimap.edina.ac.uk>, Downloaded: 2023-06-05 12:22:18.84

OS Terrain 5 [ASC geospatial data], Scale 1:10000, Tiles: tq38ne,tq38se, Updated: 20 March 2023, Ordnance Survey (GB), Using: EDINA Digimap Ordnance Survey Service, <https://digimap.edina.ac.uk>, Downloaded: 2023-06-05 12:22:18.84

OS MasterMap Water Network [GML3 geospatial data], Scale 1:2500, Tiles: tq38se,tq38ne, Updated: 20 March 2023, Ordnance Survey (GB), Using: EDINA Digimap Ordnance Survey Service, <https://digimap.edina.ac.uk>, Downloaded: 2023-06-05 12:22:18.84

OS MasterMap® Topography Layer [FileGeoDatabase geospatial data], Scale 1:1250, Tiles: GB, Updated: 8 December 2022, Ordnance Survey (GB), Using: EDINA Digimap Ordnance Survey Service, <https://digimap.edina.ac.uk>, Downloaded: 2023-06-05 12:22:18.84

OS MasterMap Greenspace [SHAPE geospatial data], Scale 1:2500, Tiles: tq38se,tq38ne, Updated: 17 April 2023, Ordnance Survey (GB), Using: EDINA Digimap Ordnance Survey Service, <https://digimap.edina.ac.uk>, Downloaded: 2023-06-05 12:22:18.84

OS MasterMap Building Height Attribute [FileGeoDatabase geospatial data], Scale 1:2500, Tiles: tq38se,tq38ne, Updated: 2 September 2021, Ordnance Survey (GB), Using: EDINA Digimap Ordnance Survey Service, <https://digimap.edina.ac.uk>, Downloaded: 2023-06-05 12:22:18.84

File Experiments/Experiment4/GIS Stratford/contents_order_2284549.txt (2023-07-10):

********************************************************************

EDINA DIGIMAP:

DIGITAL DATA SUPPLY

********************************************************************

This data is distributed under licence by:

    EDINA
    University of Edinburgh
    https://edina.ac.uk

    Tel:    0131 650 3302
    Fax:    0131 650 3308
    Email:  digimap@ed.ac.uk

---------------------------------------------------------

CONTENTS

You will have received the data files listed below, each product and area has
its own folder. Note that each data folder contains a conditions.txt file
which states the conditions for use of the data within. These conditions can
vary between different data products.

-------------------------------------------------------------------------------
Folder:           vml-raster_clr_5084715
Extent:           536438.0650649917, 183050.28609952558 - 539079.1311970917, 186079.37616572558
Date Ordered:     5 June 2023 at 12:22:18
Product:          OS VectorMap® Local
Version:          April 2023
Format:           TIFF
Theme:            Full Colour
Area:             2 tiles
Tiles:
 
Tile Name:        tq38ne_clipped
Extent:           536548.8556581866, 185000.0 - 538713.1475328258, 186079.37616572558
Last Amended:     1 April 2023
  
Tile Name:        tq38se_clipped
Extent:           536438.0650649917, 183050.28609952558 - 539079.1311970917, 185000.0
Last Amended:     1 April 2023
  
The tiles listed above have been combined to create vml-raster_5084715.tif.
  -------------------------------------------------------------------------------
Folder:           terrain-5-dtm_5084714
Extent:           536438.0650649917, 183050.28609952558 - 539079.1311970917, 186079.37616572558
Date Ordered:     5 June 2023 at 12:22:18
Product:          OS Terrain 5
Version:          April 2023
Format:           ASC
Theme:            N/A
Area:             2 tiles
Tiles:
 
Tile Name:        tq38ne
Extent:           535000.0, 185000.0 - 540000.0, 190000.0
Last Amended:     28 August 2022
  
Tile Name:        tq38se
Extent:           535000.0, 180000.0 - 540000.0, 185000.0
Last Amended:     28 August 2022
    -------------------------------------------------------------------------------
Folder:           MasterMap Water Network_5084713
Extent:           536438.0650649917, 183050.28609952558 - 539079.1311970917, 186079.37616572558
Date Ordered:     5 June 2023 at 12:22:18
Product:          OS MasterMap Water Network
Version:          April 2023
Format:           GML3
Theme:            N/A
Area:             2 tiles
Tiles:
 
Tile Name:        tq38se
Extent:           535000.0, 180000.0 - 540000.0, 185000.0
Last Amended:     20 March 2023
  
Tile Name:        tq38ne
Extent:           535000.0, 185000.0 - 540000.0, 190000.0
Last Amended:     20 March 2023
    -------------------------------------------------------------------------------
Folder:           mastermap-topo_5084712
Extent:           536438.0650649917, 183050.28609952558 - 539079.1311970917, 186079.37616572558
Date Ordered:     5 June 2023 at 12:22:18
Product:          OS MasterMap® Topography Layer
Version:          December 2022
Format:           FileGeoDatabase
Theme:            N/A
Area:             4.1147176757860855 square kilometres
Layers:
                  Administrative Boundaries
                  Buildings
                  Land
                  Rail
                  Roads, Tracks And Paths
                  Structures
                  Terrain And Height
                  Water
Chunks:
 
Filename:         mastermap-topo_5084712/mastermap-topo_5084712.gdb
Extent:           536438.0650649917, 183050.28609952558 - 539079.1311970917, 186079.37616572558
Last Amended:     8 December 2022
    -------------------------------------------------------------------------------
Folder:           MasterMap Greenspace_5084711
Extent:           536438.0650649917, 183050.28609952558 - 539079.1311970917, 186079.37616572558
Date Ordered:     5 June 2023 at 12:22:18
Product:          OS MasterMap Greenspace
Version:          April 2023
Format:           SHAPE
Theme:            N/A
Area:             2 tiles
Tiles:
 
Tile Name:        tq38se
Extent:           535000.0, 180000.0 - 540000.0, 185000.0
Last Amended:     17 April 2023
  
Tile Name:        tq38ne
Extent:           535000.0, 185000.0 - 540000.0, 190000.0
Last Amended:     17 April 2023
    -------------------------------------------------------------------------------
Folder:           mastermap_building_heights_5084710
Extent:           536438.0650649917, 183050.28609952558 - 539079.1311970917, 186079.37616572558
Date Ordered:     5 June 2023 at 12:22:18
Product:          OS MasterMap Building Height Attribute
Version:          October 2021
Format:           FileGeoDatabase
Theme:            N/A
Area:             2 tiles
Tiles:
 
Tile Name:        tq38se
Extent:           535000.0, 180000.0 - 540000.0, 185000.0
Last Amended:     2 September 2021
  
Tile Name:        tq38ne
Extent:           535000.0, 185000.0 - 540000.0, 190000.0
Last Amended:     2 September 2021

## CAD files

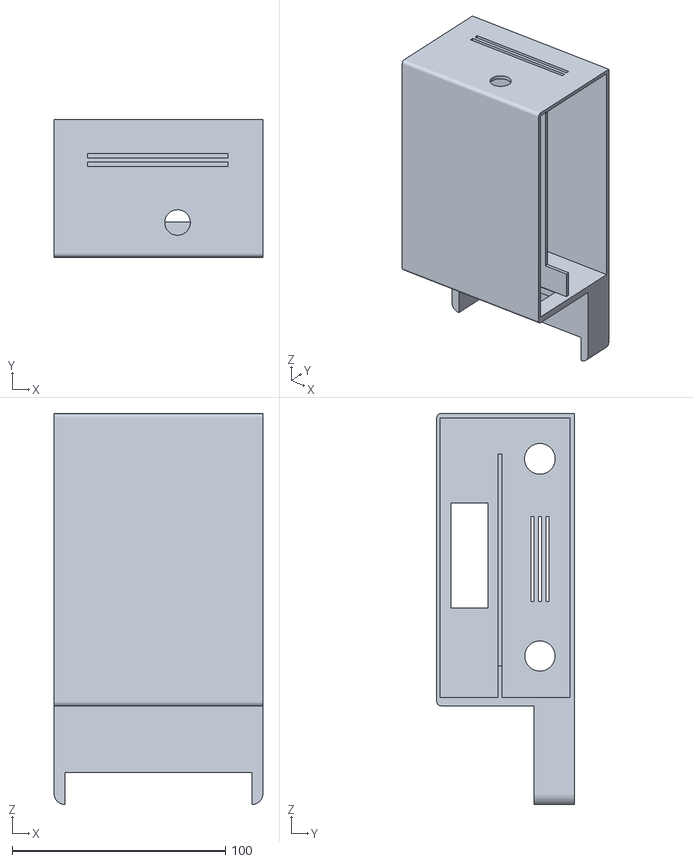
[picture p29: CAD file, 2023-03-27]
Assets/3D Enclosures/Gateway-case/GatewayCase-v5.stl
97.9 x 64.5 x 183.4

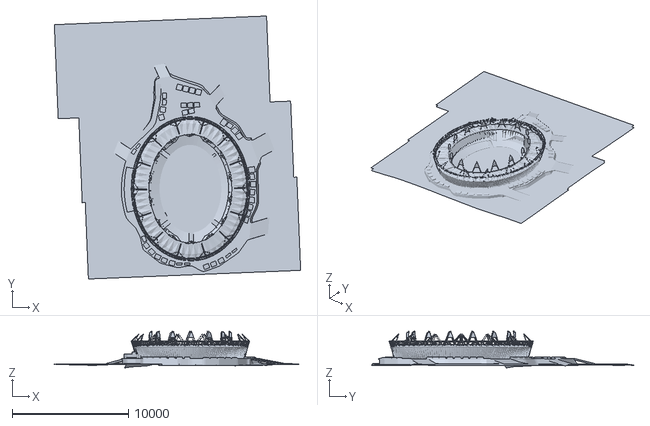
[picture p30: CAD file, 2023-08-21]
Assets/QEOP 3D models/LondonStadium/LondonStadium.stl
21190.8 x 22626.7 x 3175.5

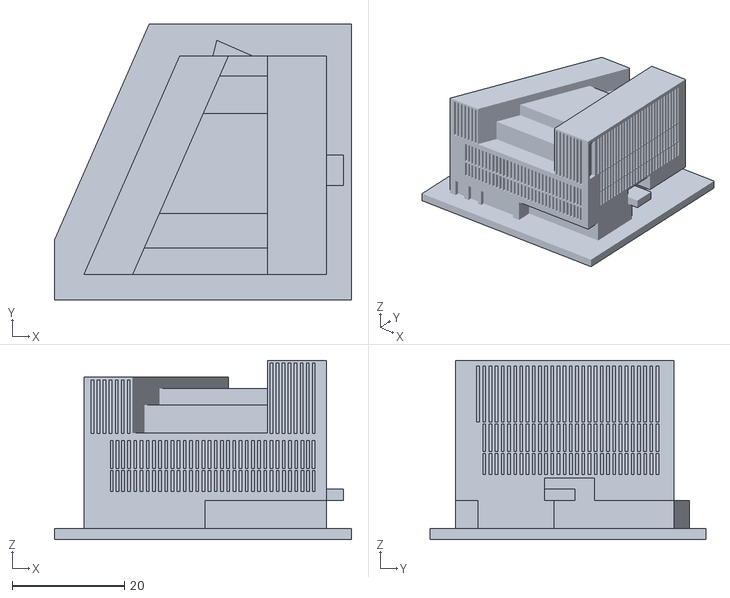
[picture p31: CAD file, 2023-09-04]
Assets/QEOP 3D models/Marshgate/Marshgate v15.stl
53.0 x 49.3 x 32.0

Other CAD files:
Assets/3D Enclosures/Gateway-case/GatewayCase-v6.f3d
Assets/QEOP 3D models/Marshgate/Marshgate v15.f3d

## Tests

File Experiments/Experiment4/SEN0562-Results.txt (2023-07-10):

LUX:503.33lx
LUX:503.33lx
LUX:503.33lx
LUX:503.33lx
LUX:501.67lx
LUX:384.17lx
LUX:179.17lx
LUX:122.50lx
LUX:75.00lx
LUX:58.33lx
LUX:45.00lx
LUX:494.17lx
LUX:498.33lx
LUX:498.33lx
LUX:497.50lx
LUX:498.33lx
LUX:498.33lx
LUX:497.50lx
LUX:495.83lx
LUX:500.83lx
LUX:503.33lx
LUX:502.50lx
LUX:501.67lx
LUX:500.83lx
LUX:500.00lx
LUX:499.17lx
LUX:494.17lx
LUX:450.00lx
LUX:500.83lx
LUX:500.00lx
LUX:749.17lx
LUX:984.17lx
LUX:952.50lx
LUX:887.50lx
LUX:954.17lx
LUX:893.33lx
LUX:1005.00lx
LUX:947.50lx
LUX:513.33lx
LUX:514.17lx
LUX:514.17lx
LUX:513.33lx
LUX:514.17lx
LUX:513.33lx
LUX:514.17lx
LUX:514.17lx
LUX:514.17lx
LUX:514.17lx
LUX:513.33lx
LUX:514.17lx
LUX:514.17lx
LUX:513.33lx
LUX:511.67lx
LUX:513.33lx
LUX:515.83lx
LUX:515.00lx
LUX:515.00lx
LUX:515.83lx
LUX:515.83lx
LUX:515.83lx
LUX:515.83lx
LUX:515.83lx
LUX:515.83lx
LUX:515.83lx
LUX:516.67lx
LUX:1140.00lx ---- My UV Light 
LUX:1105.00lx

LUX:1401.67lx
LUX:9445.83lx
LUX:15988.33lx
LUX:14477.50lx
LUX:14944.17lx
LUX:15064.17lx ---- iPhone flash light
LUX:15775.00lx
LUX:14371.67lx
LUX:14654.17lx
LUX:15449.17lx
LUX:15152.50lx
LUX:15201.67lx
LUX:14820.00lx
LUX:14240.00lx
LUX:13355.83lx
LUX:12422.50lx
LUX:14521.67lx
LUX:23465.00lx

LUX:3190.83lx
LUX:3190.83lx
LUX:3191.67lx
LUX:3187.50lx
LUX:3191.67lx
LUX:3191.67lx
LUX:3095.00lx
LUX:3201.67lx
LUX:3935.83lx
LUX:5630.83lx
LUX:6466.67lx
LUX:7622.50lx
LUX:15475.83lx
LUX:25555.00lx
LUX:32275.83lx
LUX:40007.50lx --- Sunlight
LUX:45238.33lx
LUX:44230.83lx
LUX:44182.50lx
LUX:44013.33lx
LUX:44029.16lx
LUX:44236.66lx
LUX:44287.50lx
LUX:44321.66lx
LUX:43875.00lx
LUX:33621.66lx
LUX:19250.83lx
LUX:11835.83lx
LUX:2860.00lx
LUX:2735.83lx
LUX:2764.17lx

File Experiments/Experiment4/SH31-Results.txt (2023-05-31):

SHT31 test - My room in OPS
Heater Enabled State: DISABLED
Temp *C = 25.80		Hum. % = 39.69
Temp *C = 25.78		Hum. % = 39.70
Temp *C = 25.77		Hum. % = 39.70
Temp *C = 25.78		Hum. % = 39.70
Temp *C = 25.78		Hum. % = 39.72
Temp *C = 25.80		Hum. % = 39.73
Temp *C = 25.81		Hum. % = 40.84
Temp *C = 25.80		Hum. % = 44.29
Temp *C = 25.84		Hum. % = 46.42
Temp *C = 25.80		Hum. % = 46.95
Temp *C = 25.80		Hum. % = 46.96
Temp *C = 25.80		Hum. % = 46.58
Temp *C = 25.81		Hum. % = 46.00
Temp *C = 25.81		Hum. % = 45.58
Temp *C = 25.81		Hum. % = 45.04
Temp *C = 25.81		Hum. % = 44.74
Temp *C = 25.84		Hum. % = 46.17
Temp *C = 25.81		Hum. % = 48.91
Temp *C = 25.84		Hum. % = 51.12
Temp *C = 25.81		Hum. % = 53.24
Temp *C = 25.84		Hum. % = 53.71
Temp *C = 25.82		Hum. % = 52.96
Temp *C = 25.82		Hum. % = 51.59
Temp *C = 25.84		Hum. % = 51.13
Temp *C = 25.84		Hum. % = 51.91
Temp *C = 25.82		Hum. % = 52.32
Temp *C = 25.82		Hum. % = 52.66
Temp *C = 25.84		Hum. % = 54.66
Temp *C = 25.86		Hum. % = 57.65
Temp *C = 25.85		Hum. % = 60.24
Temp *C = 25.86		Hum. % = 62.41
Heater Enabled State: ENABLED
Temp *C = 25.98		Hum. % = 64.10
Temp *C = 27.47		Hum. % = 64.31
Temp *C = 27.92		Hum. % = 62.24
Temp *C = 28.19		Hum. % = 59.15
Temp *C = 28.36		Hum. % = 55.91
Temp *C = 28.53		Hum. % = 52.90
Temp *C = 28.67		Hum. % = 49.76
Temp *C = 28.75		Hum. % = 46.94
Temp *C = 28.87		Hum. % = 44.63
Temp *C = 28.95		Hum. % = 42.69
Temp *C = 29.04		Hum. % = 41.17
Temp *C = 29.10		Hum. % = 39.91
Temp *C = 29.18		Hum. % = 38.73
Temp *C = 29.24		Hum. % = 37.61
Temp *C = 29.32		Hum. % = 36.78
Temp *C = 29.39		Hum. % = 36.04
Temp *C = 29.45		Hum. % = 35.38
Temp *C = 29.51		Hum. % = 34.83
Temp *C = 29.58		Hum. % = 34.34
Temp *C = 29.65		Hum. % = 33.98
Temp *C = 29.67		Hum. % = 33.61
Temp *C = 29.73		Hum. % = 33.38
Temp *C = 29.80		Hum. % = 34.08
Temp *C = 29.83		Hum. % = 34.91
Temp *C = 29.89		Hum. % = 35.09
Temp *C = 29.94		Hum. % = 34.86
Temp *C = 29.99		Hum. % = 34.41
Temp *C = 30.03		Hum. % = 33.92
Temp *C = 30.10		Hum. % = 33.43
Temp *C = 30.13		Hum. % = 33.01
Heater Enabled State: DISABLED
Temp *C = 30.09		Hum. % = 32.63
Temp *C = 28.60		Hum. % = 32.56
Temp *C = 28.19		Hum. % = 33.06
Temp *C = 27.98		Hum. % = 33.65
Temp *C = 27.82		Hum. % = 34.18
Temp *C = 27.71		Hum. % = 34.62
Temp *C = 27.65		Hum. % = 34.99
Temp *C = 27.55		Hum. % = 35.32
Temp *C = 27.49		Hum. % = 35.61
Temp *C = 27.41		Hum. % = 35.82
Temp *C = 27.38		Hum. % = 36.02
Temp *C = 27.34		Hum. % = 36.16
Temp *C = 27.30		Hum. % = 36.32
Temp *C = 27.24		Hum. % = 36.50
Temp *C = 27.18		Hum. % = 36.58
Temp *C = 27.17		Hum. % = 36.64
Temp *C = 27.12		Hum. % = 36.75
Temp *C = 27.08		Hum. % = 36.85
Temp *C = 27.06		Hum. % = 36.91
Temp *C = 27.00		Hum. % = 37.01
Temp *C = 26.98		Hum. % = 37.06
Temp *C = 26.94		Hum. % = 37.15
Temp *C = 26.91		Hum. % = 39.55
Temp *C = 26.90		Hum. % = 45.27
Temp *C = 26.88		Hum. % = 50.70
Temp *C = 26.87		Hum. % = 54.66
Temp *C = 26.84		Hum. % = 57.50
Temp *C = 26.82		Hum. % = 59.24
Temp *C = 26.79		Hum. % = 59.13
Temp *C = 26.77		Hum. % = 57.92
Heater Enabled State: ENABLED
Temp *C = 26.86		Hum. % = 55.89
Temp *C = 28.35		Hum. % = 53.40
Temp *C = 28.75		Hum. % = 50.03
Temp *C = 29.00		Hum. % = 46.75
Temp *C = 29.16		Hum. % = 43.95
Temp *C = 29.29		Hum. % = 41.43
Temp *C = 29.36		Hum. % = 39.44
Temp *C = 29.49		Hum. % = 37.86
Temp *C = 29.55		Hum. % = 36.66
Temp *C = 29.65		Hum. % = 35.73
Temp *C = 29.67		Hum. % = 35.00
Temp *C = 29.75		Hum. % = 34.32
Temp *C = 29.83		Hum. % = 33.76
Temp *C = 29.89		Hum. % = 33.36
Temp *C = 29.92		Hum. % = 33.04
Temp *C = 29.97		Hum. % = 32.73
Temp *C = 30.06		Hum. % = 32.48
Temp *C = 30.09		Hum. % = 32.29
Temp *C = 30.14		Hum. % = 32.10
Temp *C = 30.17		Hum. % = 31.93
Temp *C = 30.20		Hum. % = 31.80
Temp *C = 30.27		Hum. % = 31.68
Temp *C = 30.28		Hum. % = 31.54
Temp *C = 30.34		Hum. % = 31.43
Temp *C = 30.38		Hum. % = 31.31
Temp *C = 30.43		Hum. % = 31.22
Temp *C = 30.45		Hum. % = 31.16
Temp *C = 30.49		Hum. % = 31.09
Temp *C = 30.48		Hum. % = 31.06
Temp *C = 30.53		Hum. % = 30.94
Heater Enabled State: DISABLED
Temp *C = 30.48		Hum. % = 30.89
Temp *C = 29.01		Hum. % = 31.05
Temp *C = 28.61		Hum. % = 31.63
Temp *C = 28.37		Hum. % = 32.33
Temp *C = 28.20		Hum. % = 33.03
Temp *C = 28.09		Hum. % = 33.56
Temp *C = 27.99		Hum. % = 34.00
Temp *C = 27.89		Hum. % = 34.35
Temp *C = 27.81		Hum. % = 34.69
Temp *C = 27.75		Hum. % = 34.94
Temp *C = 27.71		Hum. % = 35.21
Temp *C = 27.63		Hum. % = 35.39
Temp *C = 27.59		Hum. % = 35.48
Temp *C = 27.52		Hum. % = 35.66
Temp *C = 27.51		Hum. % = 35.76
Temp *C = 27.45		Hum. % = 35.81
Temp *C = 27.39		Hum. % = 35.91
Temp *C = 27.39		Hum. % = 36.02
Temp *C = 27.33		Hum. % = 36.13
Temp *C = 27.27		Hum. % = 36.21
Temp *C = 27.21		Hum. % = 36.28
Temp *C = 27.21		Hum. % = 36.35
Temp *C = 27.14		Hum. % = 36.43
Temp *C = 27.15		Hum. % = 36.48
Temp *C = 27.10		Hum. % = 36.61
Temp *C = 27.08		Hum. % = 36.62
Temp *C = 27.06		Hum. % = 36.72
Temp *C = 27.01		Hum. % = 36.76
Temp *C = 26.97		Hum. % = 36.81
Temp *C = 26.94		Hum. % = 36.88
Heater Enabled State: ENABLED
Temp *C = 27.00		Hum. % = 36.90
Temp *C = 28.50		Hum. % = 36.81
Temp *C = 28.91		Hum. % = 36.12
Temp *C = 29.12		Hum. % = 35.35
Temp *C = 29.31		Hum. % = 34.70
Temp *C = 29.43		Hum. % = 34.10
Temp *C = 29.55		Hum. % = 33.61
Temp *C = 29.61		Hum. % = 33.23
Temp *C = 29.70		Hum. % = 32.86
Temp *C = 29.77		Hum. % = 32.64
Temp *C = 29.83		Hum. % = 32.35
Temp *C = 29.87		Hum. % = 32.20
Temp *C = 29.96		Hum. % = 32.01
Temp *C = 30.02		Hum. % = 31.88
Temp *C = 30.06		Hum. % = 31.66
Temp *C = 30.13		Hum. % = 31.57
Temp *C = 30.14		Hum. % = 31.47
Temp *C = 30.20		Hum. % = 31.39
Temp *C = 30.24		Hum. % = 31.24
Temp *C = 30.30		Hum. % = 31.15
Temp *C = 30.35		Hum. % = 31.11
Temp *C = 30.35		Hum. % = 31.05
Temp *C = 30.40		Hum. % = 30.96
Temp *C = 30.43		Hum. % = 30.88
Temp *C = 30.47		Hum. % = 30.84
Temp *C = 30.53		Hum. % = 30.78
Temp *C = 30.55		Hum. % = 30.75
Temp *C = 30.58		Hum. % = 30.69
Temp *C = 30.64		Hum. % = 30.63
Temp *C = 30.67		Hum. % = 30.60
Heater Enabled State: DISABLED
Temp *C = 30.58		Hum. % = 30.47
Temp *C = 29.10		Hum. % = 30.71
Temp *C = 28.67		Hum. % = 31.36
Temp *C = 28.47		Hum. % = 32.12
Temp *C = 28.29		Hum. % = 32.84
Temp *C = 28.19		Hum. % = 33.35
Temp *C = 28.09		Hum. % = 33.83
Temp *C = 27.99		Hum. % = 34.20
Temp *C = 27.90		Hum. % = 34.51
Temp *C = 27.84		Hum. % = 34.70
Temp *C = 27.77		Hum. % = 34.94
Temp *C = 27.71		Hum. % = 35.06
Temp *C = 27.65		Hum. % = 35.25
Temp *C = 27.61		Hum. % = 35.44
Temp *C = 27.57		Hum. % = 35.68
Temp *C = 27.51		Hum. % = 35.83
Temp *C = 27.48		Hum. % = 36.01
Temp *C = 27.41		Hum. % = 36.09
Temp *C = 27.38		Hum. % = 36.15
Temp *C = 27.35		Hum. % = 36.23
Temp *C = 27.28		Hum. % = 36.26
Temp *C = 27.27		Hum. % = 36.30
Temp *C = 27.23		Hum. % = 36.27
Temp *C = 27.21		Hum. % = 36.39
Temp *C = 27.15		Hum. % = 36.42
Temp *C = 27.11		Hum. % = 36.47
Temp *C = 27.10		Hum. % = 36.51
Temp *C = 27.07		Hum. % = 36.55
Temp *C = 27.03		Hum. % = 36.65
Temp *C = 27.00		Hum. % = 36.67
Heater Enabled State: ENABLED
Temp *C = 27.07		Hum. % = 36.71
Temp *C = 28.57		Hum. % = 37.07
Temp *C = 28.98		Hum. % = 38.58
Temp *C = 29.22		Hum. % = 41.02
Temp *C = 29.39		Hum. % = 43.98
Temp *C = 29.55		Hum. % = 47.12
Temp *C = 29.66		Hum. % = 50.24
Temp *C = 29.79		Hum. % = 51.54
Temp *C = 29.90		Hum. % = 51.79
Temp *C = 29.96		Hum. % = 51.39
Temp *C = 30.03		Hum. % = 50.95
Temp *C = 30.07		Hum. % = 49.34
Temp *C = 30.26		Hum. % = 45.64
Temp *C = 30.67		Hum. % = 45.23
Temp *C = 31.02		Hum. % = 50.10
Temp *C = 31.25		Hum. % = 53.85
Temp *C = 31.56		Hum. % = 56.80
Temp *C = 31.69		Hum. % = 56.88
Temp *C = 31.77		Hum. % = 50.26
Temp *C = 31.81		Hum. % = 44.35
Temp *C = 31.80		Hum. % = 39.81
Temp *C = 31.84		Hum. % = 36.63
Temp *C = 31.97		Hum. % = 36.19
Temp *C = 32.20		Hum. % = 42.04
Temp *C = 32.39		Hum. % = 48.07
Temp *C = 32.61		Hum. % = 53.14
Temp *C = 32.80		Hum. % = 56.74
Temp *C = 33.13		Hum. % = 57.55
Temp *C = 33.22		Hum. % = 61.35
Temp *C = 33.30		Hum. % = 62.77
Heater Enabled State: DISABLED
Temp *C = 33.19		Hum. % = 63.44
Temp *C = 31.87		Hum. % = 63.73
Temp *C = 31.80		Hum. % = 65.26
Temp *C = 31.63		Hum. % = 66.62
Temp *C = 31.70		Hum. % = 65.35
Temp *C = 31.72		Hum. % = 67.30
Temp *C = 31.54		Hum. % = 62.48
Temp *C = 31.42		Hum. % = 54.89
Temp *C = 31.29		Hum. % = 49.53
Temp *C = 31.18		Hum. % = 48.97
Temp *C = 31.06		Hum. % = 50.34
Temp *C = 30.94		Hum. % = 52.82
Temp *C = 30.85		Hum. % = 55.50
Temp *C = 30.74		Hum. % = 58.05
Temp *C = 30.67		Hum. % = 60.33
Temp *C = 30.57		Hum. % = 62.06
Temp *C = 30.48		Hum. % = 63.50
Temp *C = 30.41		Hum. % = 64.80
Temp *C = 30.33		Hum. % = 65.75
Temp *C = 30.27		Hum. % = 66.40
Temp *C = 30.18		Hum. % = 67.04
Temp *C = 30.12		Hum. % = 67.51
Temp *C = 30.06		Hum. % = 66.70
Temp *C = 30.00		Hum. % = 65.28
Temp *C = 29.92		Hum. % = 63.92
Temp *C = 29.86		Hum. % = 61.61
Temp *C = 29.79		Hum. % = 58.40
Temp *C = 29.76		Hum. % = 54.90
Temp *C = 29.67		Hum. % = 51.52
Temp *C = 29.62		Hum. % = 48.37
Heater Enabled State: ENABLED
Temp *C = 29.65		Hum. % = 45.65
Temp *C = 31.08		Hum. % = 43.00
Temp *C = 31.47		Hum. % = 40.05
Temp *C = 31.69		Hum. % = 37.63
Temp *C = 31.80		Hum. % = 35.76
Temp *C = 31.90		Hum. % = 34.30
Temp *C = 32.00		Hum. % = 33.06
Temp *C = 32.04		Hum. % = 32.14
Temp *C = 32.10		Hum. % = 31.39
Temp *C = 32.14		Hum. % = 30.84
Temp *C = 32.18		Hum. % = 30.41
Temp *C = 32.21		Hum. % = 30.03
Temp *C = 32.23		Hum. % = 29.78
Temp *C = 32.28		Hum. % = 29.53
Temp *C = 32.28		Hum. % = 29.38
Temp *C = 32.31		Hum. % = 29.21
Temp *C = 32.35		Hum. % = 29.04
Temp *C = 32.37		Hum. % = 28.95
Temp *C = 32.39		Hum. % = 28.86
Temp *C = 32.41		Hum. % = 28.78
Temp *C = 32.42		Hum. % = 28.62
Temp *C = 32.44		Hum. % = 28.53
Temp *C = 32.45		Hum. % = 28.46
Temp *C = 32.48		Hum. % = 28.47
Temp *C = 32.49		Hum. % = 28.41
Temp *C = 32.52		Hum. % = 28.38
Temp *C = 32.55		Hum. % = 28.35
Temp *C = 32.55		Hum. % = 28.27
Temp *C = 32.57		Hum. % = 28.21
Temp *C = 32.58		Hum. % = 28.15
Heater Enabled State: DISABLED
Temp *C = 32.52		Hum. % = 28.16
Temp *C = 31.02		Hum. % = 28.36
Temp *C = 30.58		Hum. % = 29.06
Temp *C = 30.34		Hum. % = 29.71
Temp *C = 30.16		Hum. % = 30.36
Temp *C = 30.02		Hum. % = 30.86
Temp *C = 29.90		Hum. % = 31.24
Temp *C = 29.82		Hum. % = 31.63
Temp *C = 29.73		Hum. % = 31.90
Temp *C = 29.65		Hum. % = 32.13
Temp *C = 29.58		Hum. % = 32.41
Temp *C = 29.51		Hum. % = 32.55
Temp *C = 29.45		Hum. % = 32.75
Temp *C = 29.39		Hum. % = 32.83
Temp *C = 29.31		Hum. % = 32.99
Temp *C = 29.25		Hum. % = 33.04
Temp *C = 29.21		Hum. % = 33.15
Temp *C = 29.14		Hum. % = 33.27
Temp *C = 29.08		Hum. % = 33.36
Temp *C = 29.02		Hum. % = 33.51
Temp *C = 29.00		Hum. % = 33.56
Temp *C = 28.94		Hum. % = 33.53
Temp *C = 28.91		Hum. % = 33.73
Temp *C = 28.86		Hum. % = 33.83
Temp *C = 28.82		Hum. % = 33.83
Temp *C = 28.77		Hum. % = 33.95
Temp *C = 28.73		Hum. % = 33.96
Temp *C = 28.67		Hum. % = 34.05
Temp *C = 28.64		Hum. % = 34.14
Temp *C = 28.61		Hum. % = 34.18
Heater Enabled State: ENABLED
Temp *C = 28.67		Hum. % = 34.30
Temp *C = 30.14		Hum. % = 34.16
Temp *C = 30.54		Hum. % = 33.39
Temp *C = 30.72		Hum. % = 32.66
Temp *C = 30.94		Hum. % = 32.02
Temp *C = 31.03		Hum. % = 31.43
Temp *C = 31.15		Hum. % = 30.97
Temp *C = 31.22		Hum. % = 30.61
Temp *C = 31.27		Hum. % = 30.38
Temp *C = 31.35		Hum. % = 30.17
Temp *C = 31.42		Hum. % = 29.91
Temp *C = 31.47		Hum. % = 29.82
Temp *C = 31.49		Hum. % = 29.67
Temp *C = 31.56		Hum. % = 29.59
Temp *C = 31.59		Hum. % = 29.52
Temp *C = 31.62		Hum. % = 29.46
Temp *C = 31.67		Hum. % = 29.37
Temp *C = 31.72		Hum. % = 29.31
Temp *C = 31.74		Hum. % = 29.17
Temp *C = 31.79		Hum. % = 29.15
Temp *C = 31.81		Hum. % = 29.11
Temp *C = 31.87		Hum. % = 29.03
Temp *C = 31.90		Hum. % = 28.97
Temp *C = 31.91		Hum. % = 28.93
Temp *C = 31.94		Hum. % = 28.81
Temp *C = 31.98		Hum. % = 28.76
Temp *C = 32.00		Hum. % = 28.75
Temp *C = 32.04		Hum. % = 28.72
Temp *C = 32.06		Hum. % = 28.58
Temp *C = 32.08		Hum. % = 28.66
Heater Enabled State: DISABLED
Temp *C = 32.00		Hum. % = 28.58
Temp *C = 30.51		Hum. % = 28.76
Temp *C = 30.12		Hum. % = 29.40
Temp *C = 29.87		Hum. % = 30.02
Temp *C = 29.69		Hum. % = 30.65
Temp *C = 29.56		Hum. % = 31.19
Temp *C = 29.51		Hum. % = 31.59
Temp *C = 29.38		Hum. % = 31.97
Temp *C = 29.29		Hum. % = 32.25
Temp *C = 29.24		Hum. % = 32.48
Temp *C = 29.15		Hum. % = 32.68
Temp *C = 29.10		Hum. % = 32.89
Temp *C = 29.01		Hum. % = 33.02
Temp *C = 29.00		Hum. % = 33.15
Temp *C = 28.95		Hum. % = 33.32
Temp *C = 28.87		Hum. % = 33.43
Temp *C = 28.81		Hum. % = 33.49
Temp *C = 28.78		Hum. % = 33.58
Temp *C = 28.74		Hum. % = 33.73
Temp *C = 28.68		Hum. % = 33.82
Temp *C = 28.67		Hum. % = 33.92
Temp *C = 28.61		Hum. % = 34.01
Temp *C = 28.56		Hum. % = 34.10
Temp *C = 28.51		Hum. % = 34.15
Temp *C = 28.46		Hum. % = 34.27
Temp *C = 28.43		Hum. % = 34.31
Temp *C = 28.41		Hum. % = 34.37
Temp *C = 28.37		Hum. % = 34.38
Temp *C = 28.32		Hum. % = 34.52
Temp *C = 28.32		Hum. % = 34.59
Heater Enabled State: ENABLED
Temp *C = 28.39		Hum. % = 34.65
Temp *C = 29.84		Hum. % = 34.54
Temp *C = 30.23		Hum. % = 33.82
Temp *C = 30.47		Hum. % = 32.99
Temp *C = 30.65		Hum. % = 32.30
Temp *C = 30.75		Hum. % = 31.77
Temp *C = 30.85		Hum. % = 31.41
Temp *C = 30.95		Hum. % = 31.12
Temp *C = 30.99		Hum. % = 30.74
Temp *C = 31.09		Hum. % = 30.53
Temp *C = 31.14		Hum. % = 30.34
Temp *C = 31.22		Hum. % = 30.16
Temp *C = 31.25		Hum. % = 30.02
Temp *C = 31.30		Hum. % = 29.90
Temp *C = 31.33		Hum. % = 29.76
Temp *C = 31.37		Hum. % = 29.66
Temp *C = 31.43		Hum. % = 29.60
Temp *C = 31.47		Hum. % = 29.62
Temp *C = 31.50		Hum. % = 29.51
Temp *C = 31.54		Hum. % = 29.42
Temp *C = 31.59		Hum. % = 29.34

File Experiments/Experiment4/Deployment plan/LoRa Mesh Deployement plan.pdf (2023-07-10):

## Deployment Plan of a LoRa Mesh Network

## Contents

### Summary

There will be a two-phase deployment:

1. Phase 1: Test

Where: One Pool Street building
How many: 3 points total in OPS.
Locations: can be found in the last section.
Until when: getting permission to deploy in the park.
2. Phase 2: Production

Where: The Olympic Park and One Pool Street building
How many: 8 points total: 4 in QEOP, 3 in QEOP as a backup (not to be used unless needed), 1 in OPS building.
Locations: can be found in the last section.
Until when: dissertation submission.

### Node location study

According to the heatmap test (https://loramesh.yaman-ka.com/Experiments/Experiment3/Results/heatmap/) I did, LoRa mesh nodes can communicate easily on a line of sight, but when it comes to ground with different heights, things could get more complicated. (https://smartmakers.io/en/lorawan-range-part-2-range-and-coverage-of-lorawan-in-practice/)

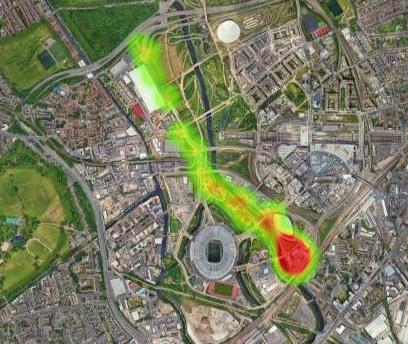
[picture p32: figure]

Figure 1 – Point-to-point LoRa RSSI test

The main difference between CASA’s past deployments and this deployment is the dependence on the industrial gateway positioned on the orbit. This gateway is positioned almost 100 meters above the ground, where in this dissertation, the nodes will be maximum 3 to 4 meters above the ground.

This means a topographic study must be done on the park to ensure the nodes are positioned in the right places to give acceptable coverage, taking in mind the cost factor of course.

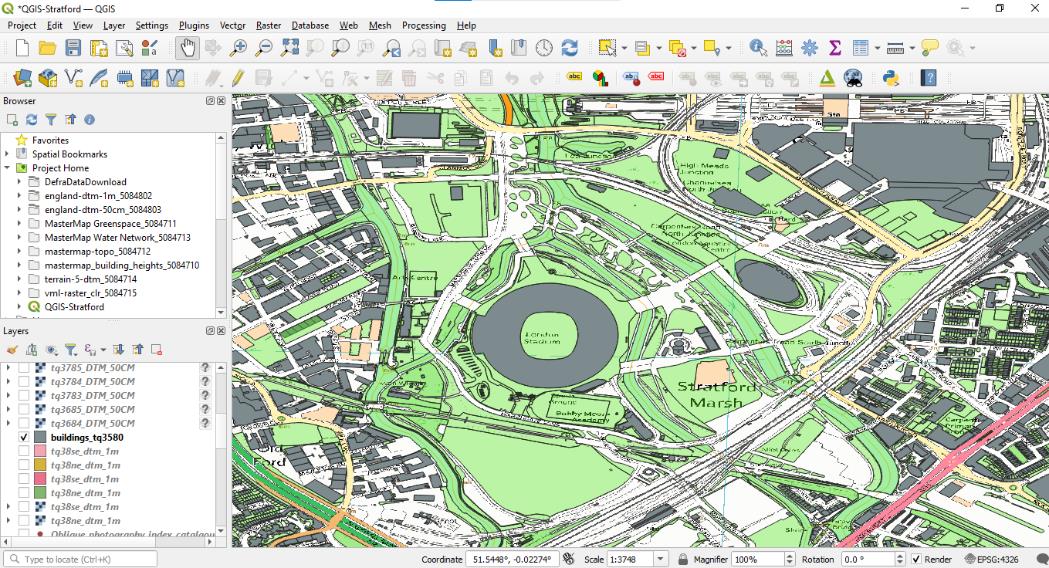
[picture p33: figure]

Figure 2 – QGIS program was used to understand building heights.

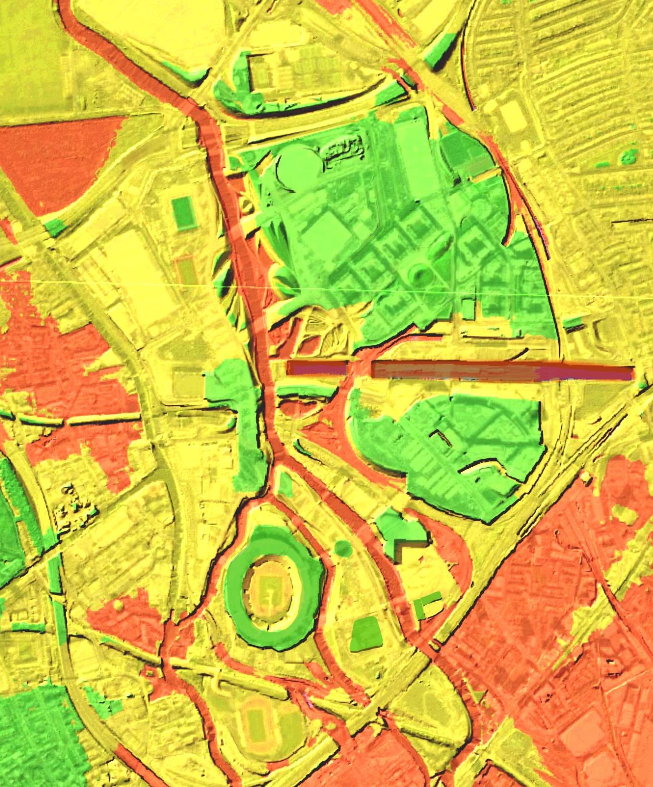
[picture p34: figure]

Figure 3 – A Topographic scan (https://environment.data.gov.uk/image/rest/services/SURVEY/LIDAR_Composite_2m_DTM_2022_Elevation/ImageServer) of Stratford and QEOP areas using LIDAR (Green colour is the highest elevation, Red is the lowest)

### Phase 1: Test phase deployment

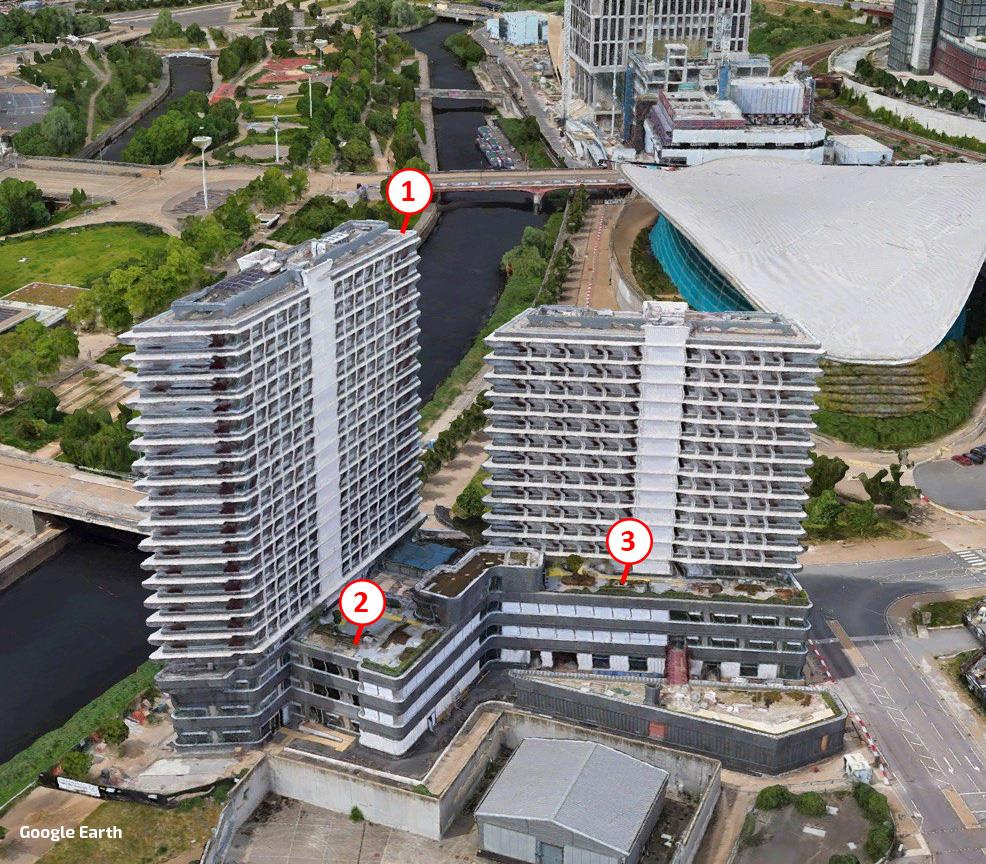
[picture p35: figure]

Figure 4 – Test phase deployment in OPS

Point (1)

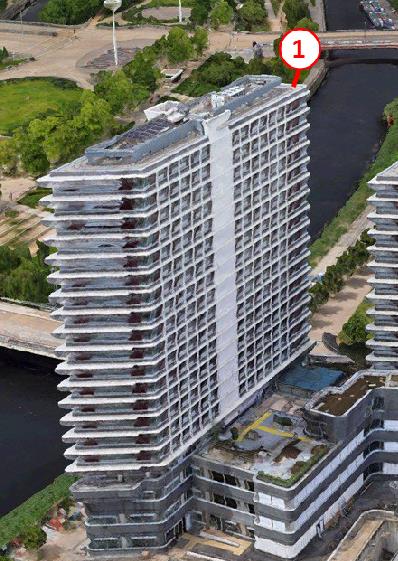
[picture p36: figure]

Figure 5 – Point 1 on Tower 1

On the roof of Tower 1, to overcome the elevation challenges. This node is to be left there during the production phase.

Point (2)

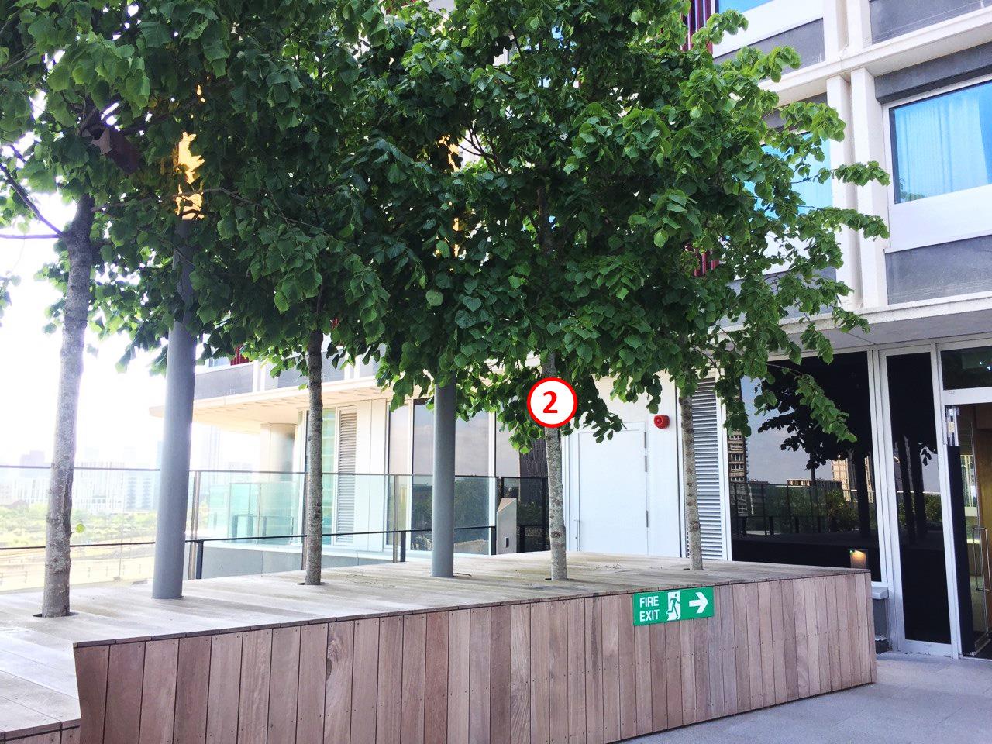
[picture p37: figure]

Figure 6 – Point 2 in OPS building on one of the trees in front of Tower 1 entrance.

Point (3)

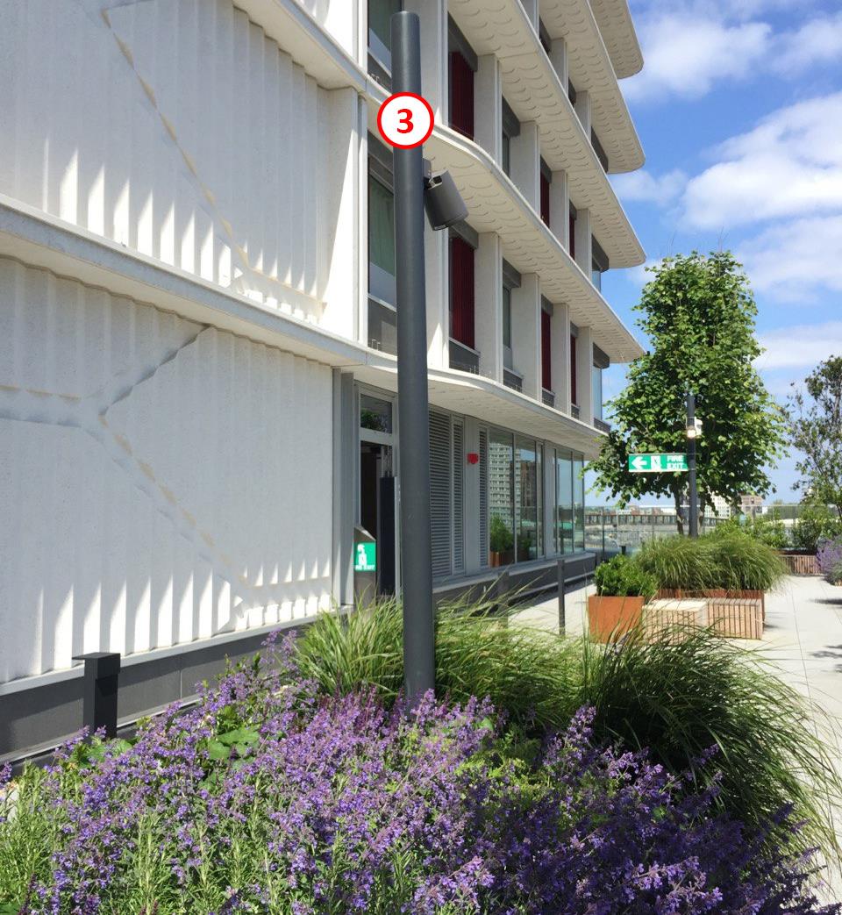
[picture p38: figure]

Figure 7 – Point 3 in OPS building on one of the poles in front of Tower 2 entrance.

### Production phase deployment

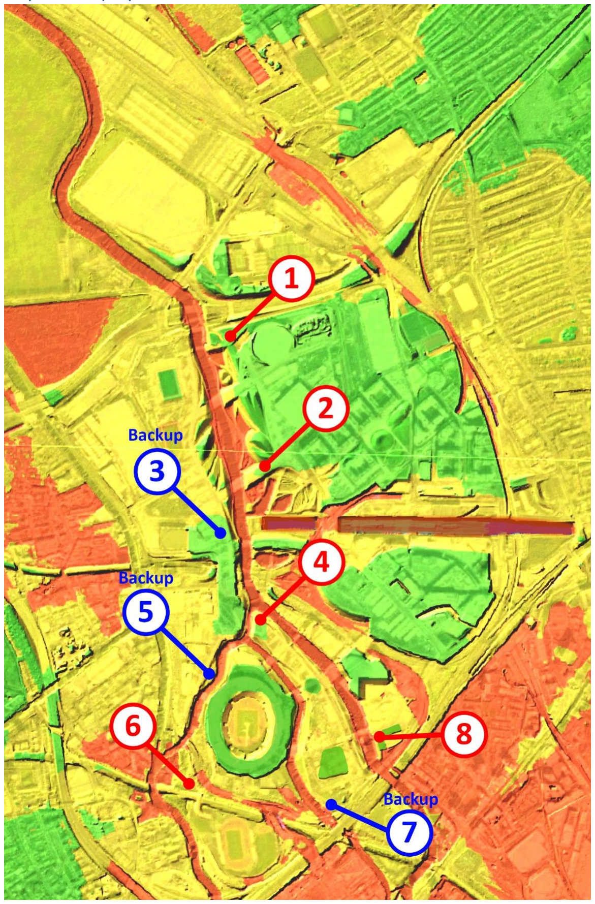
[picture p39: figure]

Figure 8 – Production deployment map. Red: main nodes, Blue: backup nodes (not deployed unless needed)

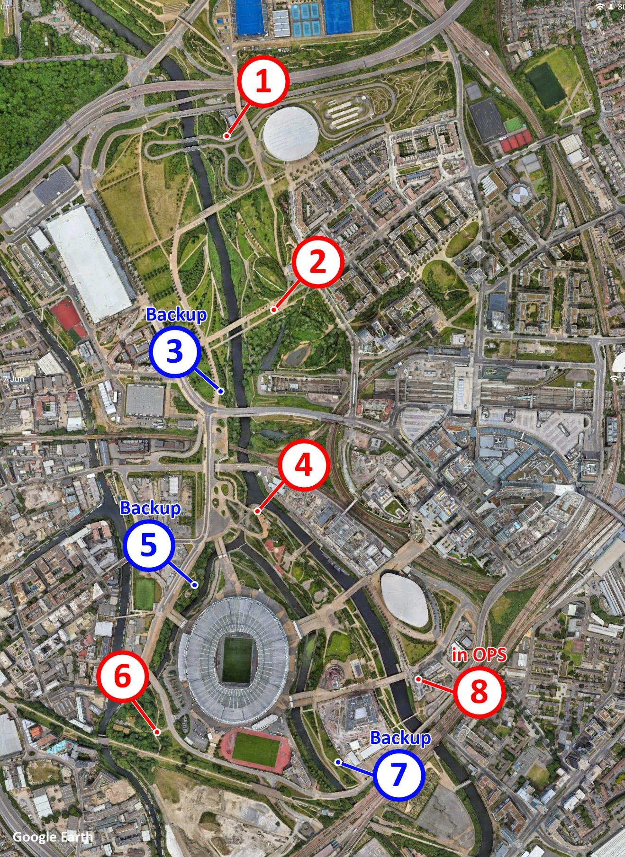
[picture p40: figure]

Figure 9 – Production deployment map with satellite view. Red: main nodes, Blue: backup nodes (not deployed unless needed)

Point (1)
- Location: https://goo.gl/maps/YNMeKN5nr37m1fR5A

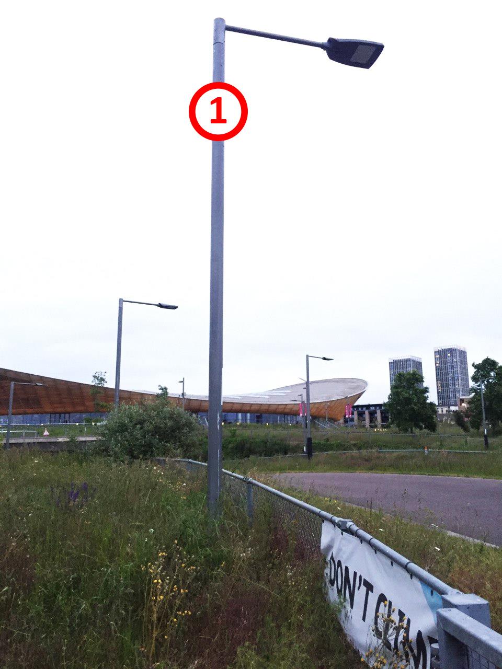
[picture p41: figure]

Figure 10 – Point 1 location on a pole.

Point (2)
- Location: https://goo.gl/maps/mALEXZ7BXhwmcBoG6


Figure 11 – Point 2 location on a pole.

Point (3) - Backup
- Location: https://goo.gl/maps/Z2oBSPZrigR1RN759


Figure 12 – Backup Point 3 location on a pole.

Point (4)
- Location: https://goo.gl/maps/7PVEuoVChoAWNGfV8


Figure 13 – Point 4 location on a pole.

Point (5) - Backup
- Location: https://goo.gl/maps/dpDjeVB95uoZ5SFZ6


Figure 14 – Backup Point 5 location on a tree.

Point (6)
- Location: https://goo.gl/maps/GrhahYLZUaSXHNdu5


Figure 15 – Point 6 location on a pole.

Point (7) - Backup
- Location: https://goo.gl/maps/U4n7qcVpkv3vwTKt6


Figure 16 – Backup Point 7 location on a tree.

Point (8)
In OPS top floor, same as Point 1 in Phase (1): testing phase.

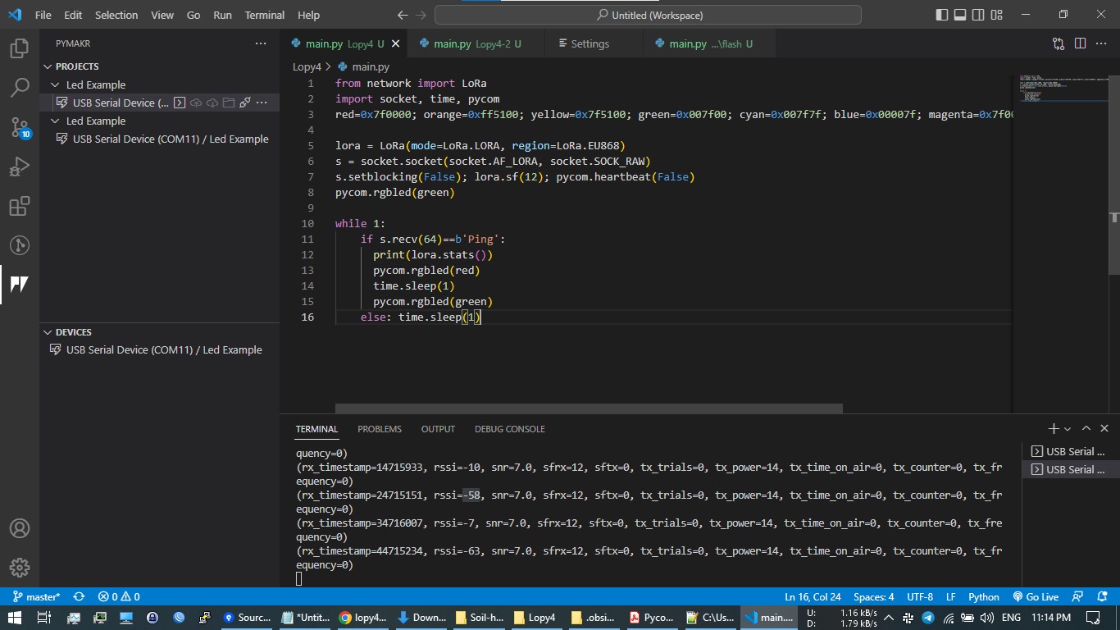
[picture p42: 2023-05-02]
Experiments/Experiment3/Assets/Receiver-terminal-RSSI-result.jpg

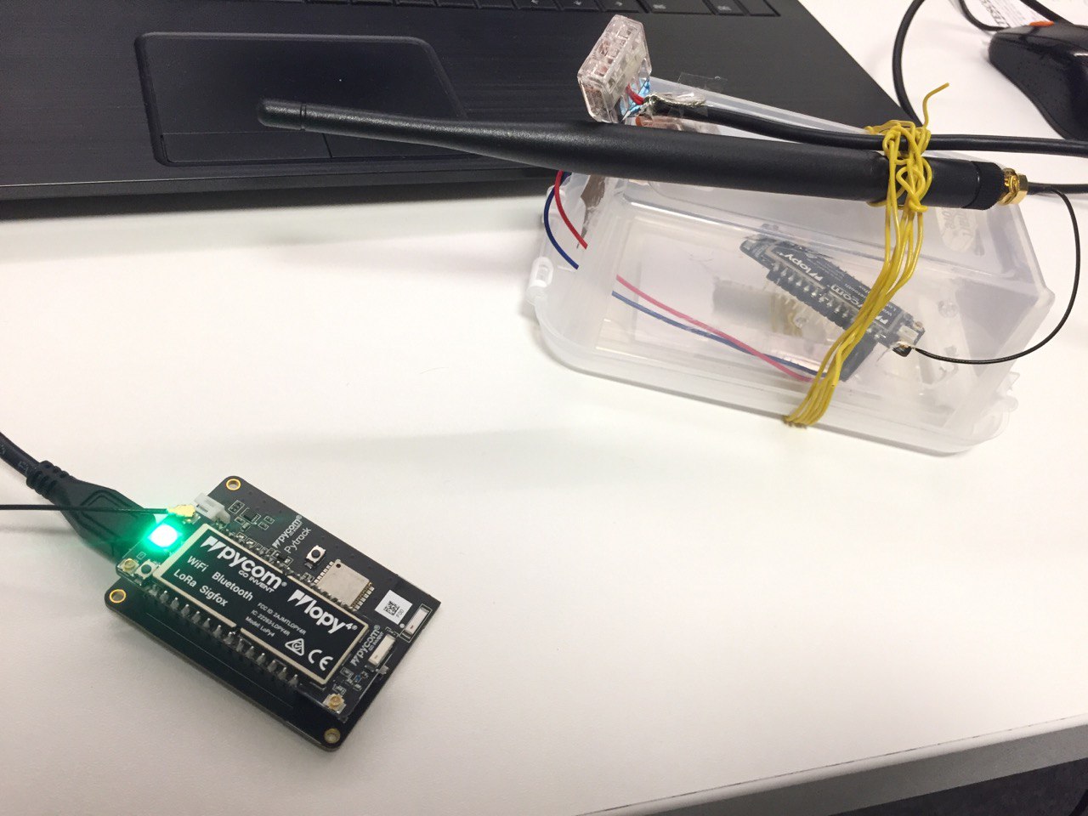
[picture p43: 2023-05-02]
Experiments/Experiment3/Assets/Sender-and-receiver-2.jpg

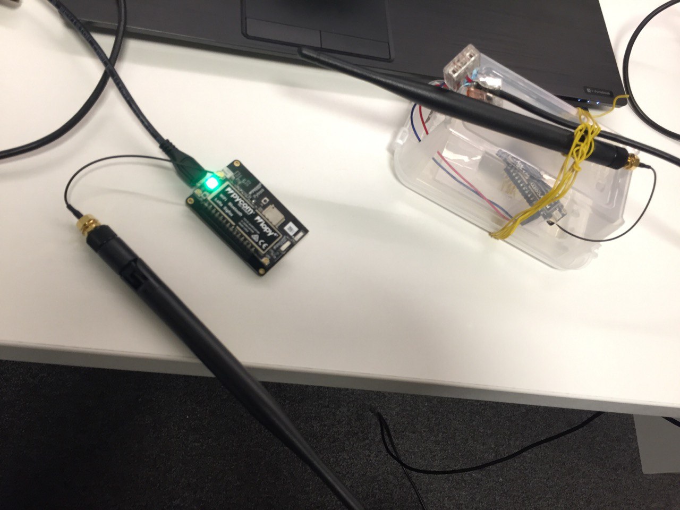
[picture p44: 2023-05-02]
Experiments/Experiment3/Assets/Sender-and-receiver-1.jpg

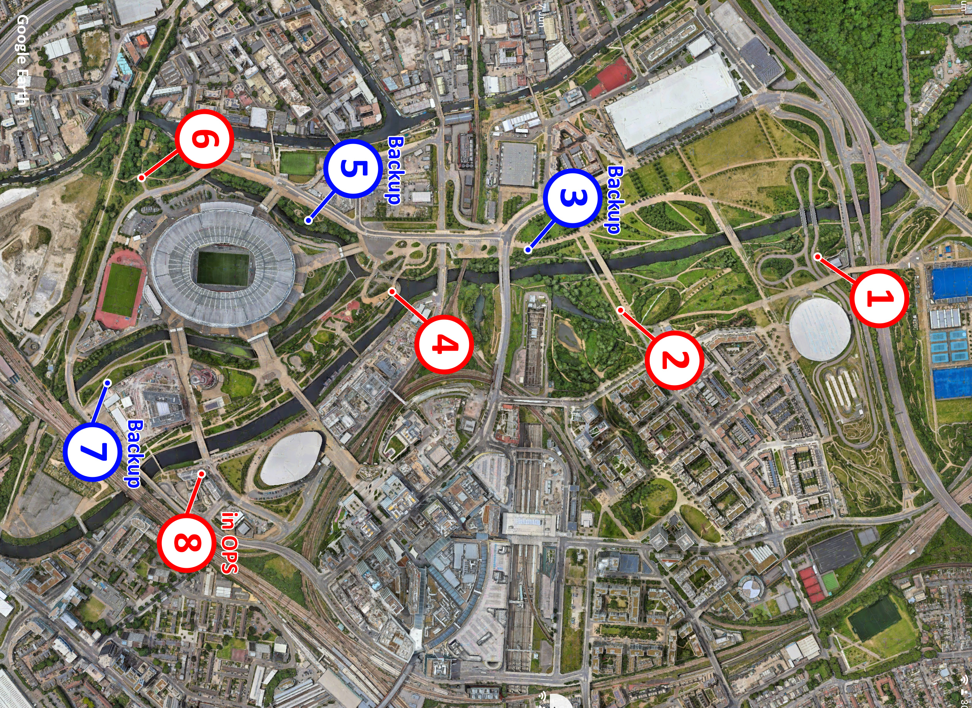
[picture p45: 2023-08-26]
Experiments/Experiment4/Deployment plan/QEOP-map.jpg

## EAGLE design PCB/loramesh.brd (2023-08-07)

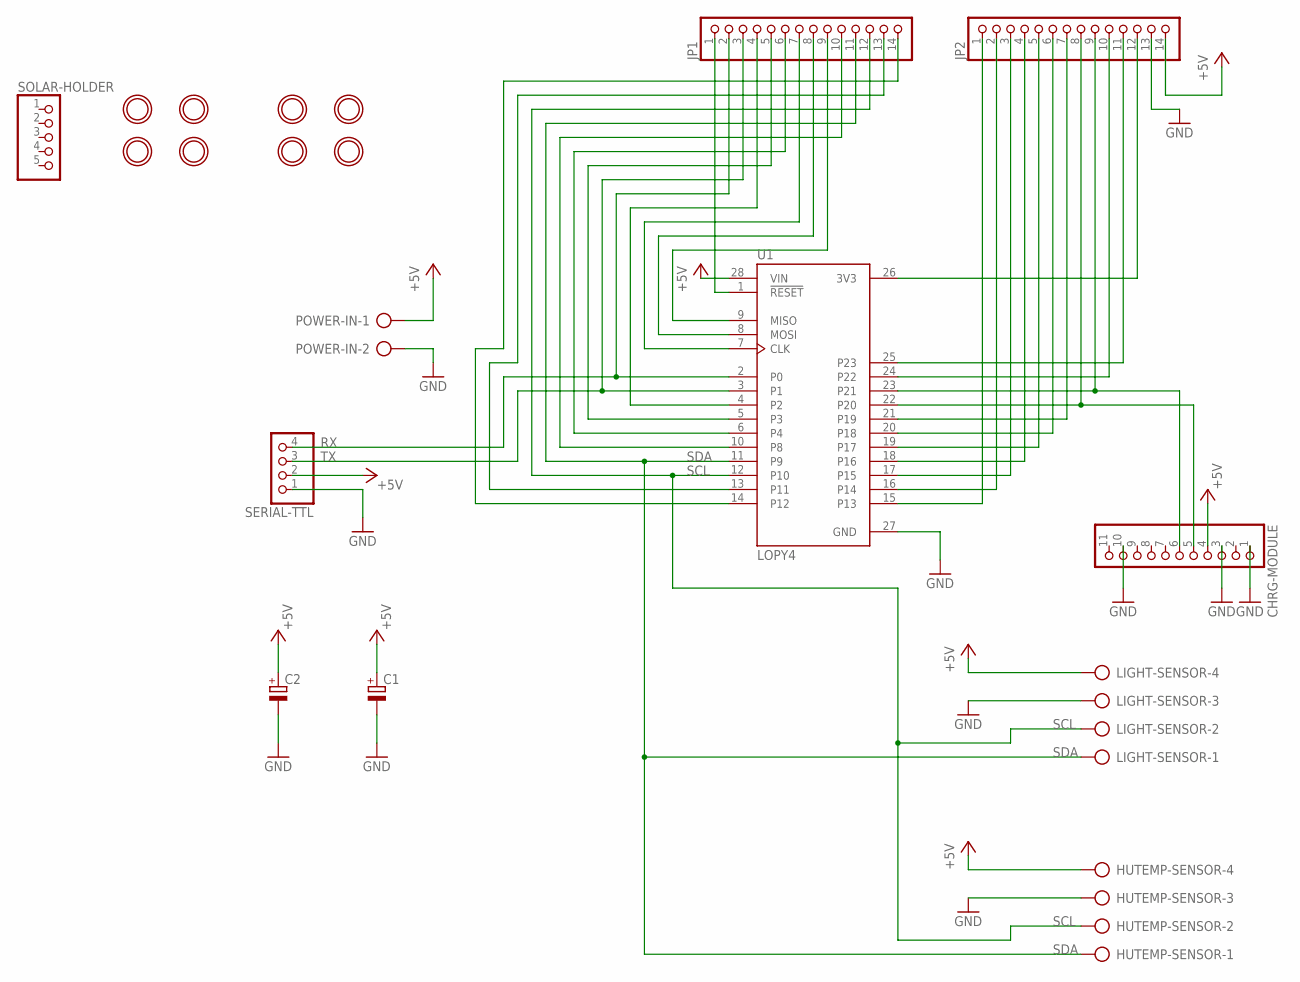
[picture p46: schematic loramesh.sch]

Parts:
C1, C2: CPOL-EUE2.5-5; E2,5-5
CHRG-MODULE: HEADER-1X1176MIL; 1X11_ROUND_76
HUTEMP-SENSOR: AK500/4
JP1, JP2: PINHD-1X14; 1X14
LIGHT-SENSOR: AK500/4
POWER-IN: AK500/2
SERIAL-TTL: PINHD-1X4; 1X04
SOLAR-HOLDER: PINHD-1X5; 1X05
U1: LOPY4; MODULE_LOPY4
U$1, U$2, U$3, U$4, U$26, U$27, U$28, U$29: MOUNTINGHOLE2.5; MOUNTINGHOLE_2.5_PLATED

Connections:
+5V: C1.+, C2.+, CHRG-MODULE.4, HUTEMP-SENSOR.4, JP2.14, LIGHT-SENSOR.4, POWER-IN.1, SERIAL-TTL.2, U1.28 (VIN)
GND: C1.-, C2.-, CHRG-MODULE.1, CHRG-MODULE.3, CHRG-MODULE.10, HUTEMP-SENSOR.3, JP2.13, LIGHT-SENSOR.3, POWER-IN.2, SERIAL-TTL.1, U1.27 (GND)
unnamed: CHRG-MODULE.5, JP2.8, U1.22 (P20)
unnamed: CHRG-MODULE.6, JP2.9, U1.23 (P21)
unnamed: JP1.1, U1.1 (!RESET)
unnamed: JP1.14, U1.14 (P12)
unnamed: JP1.13, U1.13 (P11)
unnamed: JP1.4, U1.4 (P2)
unnamed: JP1.5, U1.5 (P3)
unnamed: JP1.6, U1.6 (P4)
unnamed: JP1.7, U1.7 (CLK)
unnamed: JP1.8, U1.8 (MOSI)
unnamed: JP1.9, U1.9 (MISO)
unnamed: JP1.10, U1.10 (P8)
unnamed: JP2.1, U1.15 (P13)
unnamed: JP2.2, U1.16 (P14)
unnamed: JP2.3, U1.17 (P15)
unnamed: JP2.4, U1.18 (P16)
unnamed: JP2.5, U1.19 (P17)
unnamed: JP2.6, U1.20 (P18)
unnamed: JP2.7, U1.21 (P19)
unnamed: JP2.10, U1.24 (P22)
unnamed: JP2.11, U1.25 (P23)
unnamed: JP2.12, U1.26 (3V3)
RX: JP1.2, SERIAL-TTL.4, U1.2 (P0)
SCL: HUTEMP-SENSOR.2, JP1.12, LIGHT-SENSOR.2, U1.12 (P10)
SDA: HUTEMP-SENSOR.1, JP1.11, LIGHT-SENSOR.1, U1.11 (P9)
TX: JP1.3, SERIAL-TTL.3, U1.3 (P1)

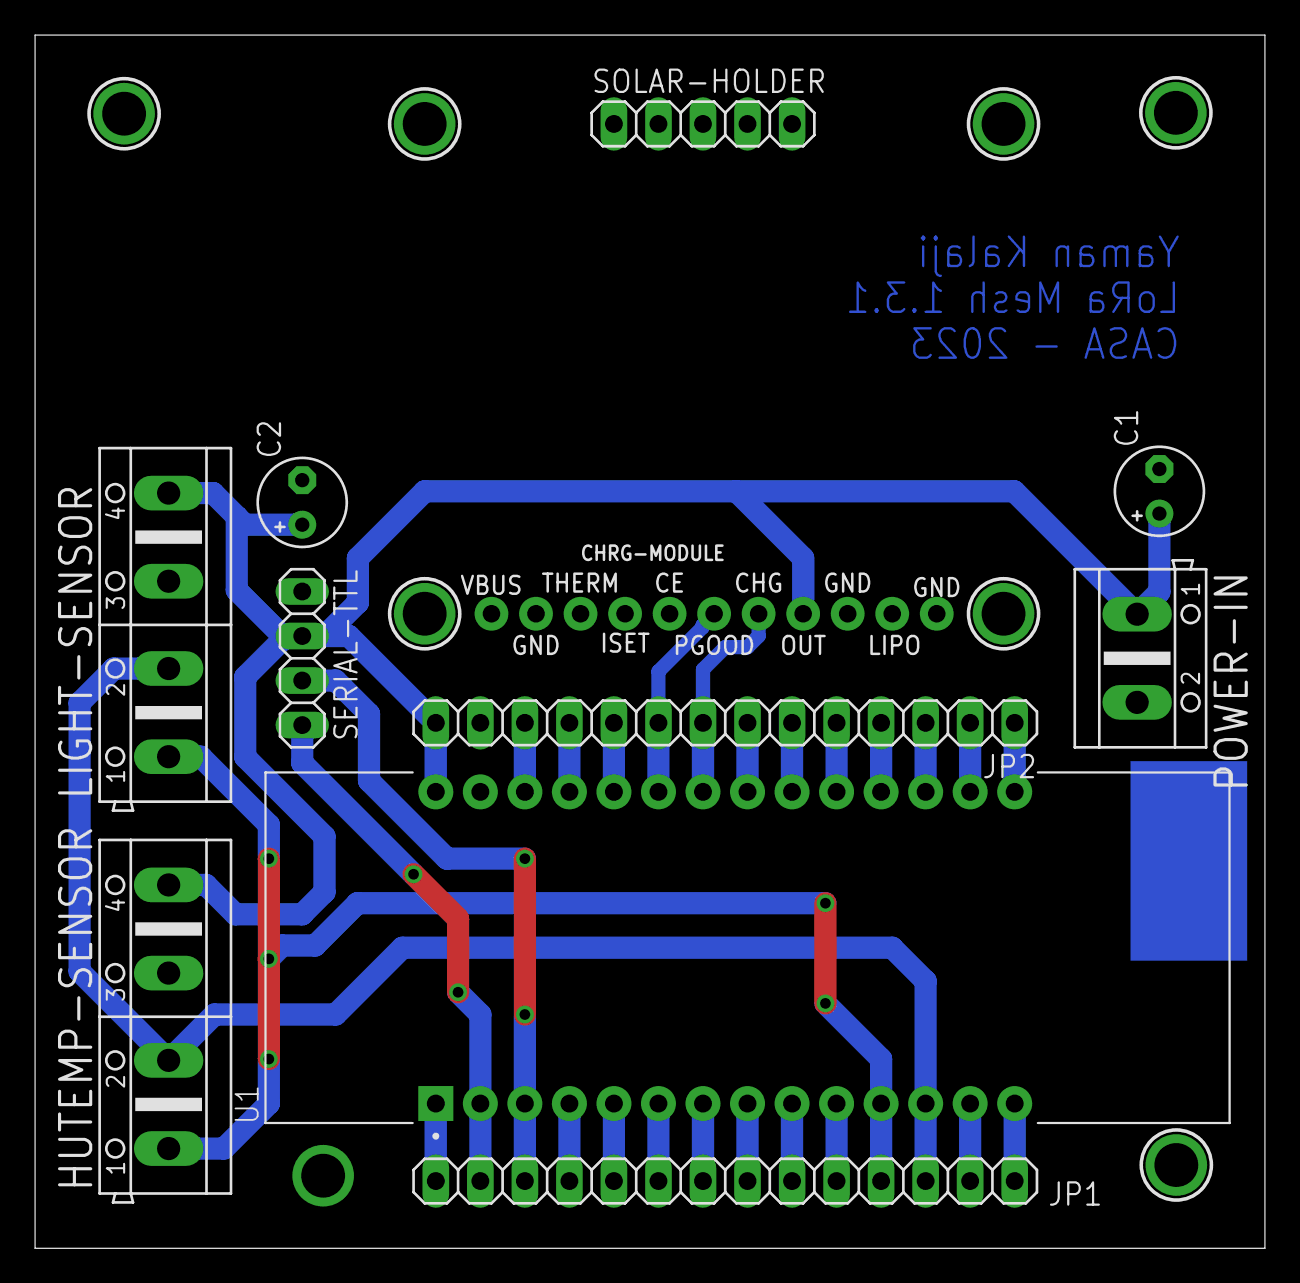
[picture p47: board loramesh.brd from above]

Board: 2 copper layers, 70.2 x 69.2 mm, 19 parts (1 on the bottom side), 28 nets.

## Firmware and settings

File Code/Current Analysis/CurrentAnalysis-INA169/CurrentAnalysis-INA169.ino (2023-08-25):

/*
 11-14-2013
 SparkFun Electronics 2013
 Shawn Hymel

 This code is public domain but you buy me a beer if you use this 
 and we meet someday (Beerware license).

 Description:

 This sketch shows how to use the SparkFun INA169 Breakout
 Board. As current passes through the shunt resistor (Rs), a
 voltage is generated at the Vout pin. Use an analog read and
 some math to determine the current. The current value is
 displayed through the Serial Monitor.

 Hardware connections:

 Uno Pin    INA169 Board    Function

 +5V        VCC             Power supply
 GND        GND             Ground
 A0         VOUT            Analog voltage measurement

 VIN+ and VIN- need to be connected inline with the positive
 DC power rail of a load (e.g. an Arduino, an LED, etc.).

 */

// Constants
const int SENSOR_PIN = A0;  // Input pin for measuring Vout
const int RS = 10;          // Shunt resistor value (in ohms)
const int VOLTAGE_REF = 3.3;  // Reference voltage for analog read

// Global Variables
int sensorValue;   // Variable to store value from analog read
float current;       // Calculated current value

void setup() {

  // Initialize serial monitor
  Serial.begin(9600);

}

void loop() {

  // Read a value from the INA169 board
  sensorValue = analogRead(SENSOR_PIN);

  // Remap the ADC value into a voltage number (5V reference)
  //sensorValue = (sensorValue * VOLTAGE_REF) / 1023;

  // Follow the equation given by the INA169 datasheet to
  // determine the current flowing through RS. Assume RL = 10k
  // Is = (Vout x 1k) / (RS x RL)
  //current = sensorValue / (10 * RS);
  float voltage= sensorValue * (3.3 / 1023.0);
  // Output value (in amps) to the serial monitor to 3 decimal
  // places
  Serial.println(sensorValue);
  Serial.print(voltage);
  Serial.println(" v");

  // Delay program for a few milliseconds
  delay(500);

}

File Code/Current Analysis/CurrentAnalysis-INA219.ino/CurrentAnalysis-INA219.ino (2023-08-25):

#include <Wire.h>
#include <Adafruit_INA219.h>

Adafruit_INA219 ina219;


void setup(void) 
{
  Serial.begin(115200);
  while (!Serial) {
      // will pause Zero, Leonardo, etc until serial console opens
      delay(1);
  }
    
  Serial.println("Hello!");
  
  // Initialize the INA219.
  // By default the initialization will use the largest range (32V, 2A).  However
  // you can call a setCalibration function to change this range (see comments).
  if (! ina219.begin()) {
    Serial.println("Failed to find INA219 chip");
    while (1) { delay(10); }
  }
  // To use a slightly lower 32V, 1A range (higher precision on amps):
  //ina219.setCalibration_32V_1A();
  // Or to use a lower 16V, 400mA range (higher precision on volts and amps):
  //ina219.setCalibration_16V_400mA();

  Serial.println("Measuring voltage and current with INA219 ...");
}

void loop(void) 
{
  float shuntvoltage = 0;
  float busvoltage = 0;
  float current_mA = 0;
  float loadvoltage = 0;
  float power_mW = 0;

  shuntvoltage = ina219.getShuntVoltage_mV();
  busvoltage = ina219.getBusVoltage_V();
  current_mA = ina219.getCurrent_mA();
  power_mW = ina219.getPower_mW();
  loadvoltage = busvoltage + (shuntvoltage / 1000);
  
  //Serial.print("Bus Voltage:   "); Serial.print(busvoltage); Serial.println(" V");
  //Serial.print("Shunt Voltage: "); Serial.print(shuntvoltage); Serial.println(" mV");
  //Serial.print("Load Voltage:  "); Serial.print(loadvoltage); Serial.println(" V");
  //Serial.print("Current:       "); Serial.print(current_mA); Serial.println(" mA");
  //Serial.print("Power:         "); Serial.print(power_mW); Serial.println(" mW");
  //Serial.println("");
  Serial.print(current_mA); Serial.println(" mA");
  delay(2000);
}

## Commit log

2023-03-27 Add Mikrotik LoRa gateway 3D case
    [RouterHolder.stl]
2023-03-27 Change router case name to be v1
    [RouterHolder-v1.stl]
2023-03-27 Add v2 of Router Holder
    [RouterHolder-v1.stl, RouterHolder-v2.stl]
2023-03-27 Add v3 of Gateway case
    [GatewayCase-v3.stl, RouterHolder-v2.stl]
2023-03-27 V4 of gateway case
    [GatewayCase-v3.stl, GatewayCase-v4.stl]
2023-03-27 V5 of gateway case
    [GatewayCase-v4.stl, GatewayCase-v5.stl]
2023-03-27 Add Fusion 360 file of Gateway case v6
    [GatewayCase-v6.f3d]
2023-03-27 Add the code for LoRa heatmap experiment in One Pool Street, London
2023-04-13 Add the results of the LoRa heatmap experiment #2
2023-05-02 Complete files and folders restructuring
    [GatewayCase-v5.stl, GatewayCase-v6.f3d]
2023-05-02 Added an interactive heatmap with the 3rd experiment results
    [Experiment3-LoRa-RSSI-heatmap-QEOP-OPS.csv]
2023-05-31 Add a SH31 temperature and humidity test script & results
2023-05-31 Try to make the light sensor work, the code doesn't work because it contains a special character
    [SEN0562-LightSensor.ino]
2023-05-31 Try to fix the code by replacing the special character with its binary equivalent - not working
    [SEN0562-LightSensor.ino]
2023-05-31 Added the datasheet for the main IC of the light sensor
2023-05-31 Found the right I2C code, now the code is working
2023-05-31 Add sensor light results
2023-07-10 Add some raw results for the light sensor (SEN0562)
2023-07-10 Disable the heater to get accurate results
2023-07-10 Try to merge all sensors
2023-08-02 Fix a bug in the Pycom's code, maybe the example I'm using is old
    [main.py]
2023-08-05 Remove humidity sensor and start from the beginning again
2023-08-05 Temperature sensor is working now via I2C
2023-08-05 Refactor the all sensors code
2023-08-07 Add PCB files (sent to China)
    [DRILEGEND.CFG, loramesh.brd, loramesh.sch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]
2023-08-09 Restructure 3D printed files
    [GatewayCase-v5.stl, GatewayCase-v6.f3d]
2023-08-09 Add exported photos of the PCB
2023-08-09 Add the generated CAM outputs for later CNC job
    [copper_bottom.gbr, copper_top.gbr, drill_1_16.xln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]
2023-08-09 Add FlatCAM PCB project file for the CNC machine
2023-08-11 Added settings used to mill the first PCB using Carvey CNC machine, also reached a conclusion after breaking 3 pits that I need a V shaped pit for etching
2023-08-15 Add steps documentation for manufacturing a PCB using a CNC
2023-08-17 Add the printed version of the Aquatic Centre
2023-08-17 Add the print optimised version of the Aquatic Centre
2023-08-17 Add heatmap webpage code
    [Experiment3-LoRa-RSSI-heatmap-QEOP-OPS.csv]
2023-08-19 My SHT30 Python implementation didn't fully work, found a library for that
    [main.py, sht30.py]
2023-08-19 Modify the SHT30 library to be compatible with my sensor and Lopy4
2023-08-19 Connect sensors to MQTT and my InfluxDB
2023-08-21 Add London Stadium to the QEOP 3D models
    [LondonStadium.stl]
2023-08-25 Change folder name
    [Experiment3-LoRa-RSSI-heatmap-QEOP-OPS.csv]
2023-08-25 Add current analysis code
2023-08-25 Add current consumption results
    [BroadRouterNode.csv, Current-child-with-deep-sleep-one-spike.csv, Current-child-with-deep-sleep.csv]
2023-08-25 Add the code for current analysis using INA169
2023-08-25 Add the schematic for current analysis circuit
    [Current circuit.sch]
2023-08-25 Add PCB images
2023-08-26 Add the calibrated Base Map of the Data Table
2023-08-28 Organise the datasets into one folder
    [Current-Analysis-Border-Router-Node.csv, Current-Analysis-Child-Node-with-deep-sleep.csv, Humditiy-QEOP-2023-08-20-to-2023-08-23.csv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]
2023-09-04 Finished designing a 3D model for Marshgate from scratch
    [Marshgate v15.f3d, Marshgate v15.stl]
